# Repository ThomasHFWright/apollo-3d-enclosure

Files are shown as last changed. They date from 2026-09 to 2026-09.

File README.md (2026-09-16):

# Apollo R PRO-1 fixed-angle wall and corner enclosure

**Compact corner placement and independent wall offsets are included:** see the [corner guide](docs/COMPACT-CORNER.md). Each example retains its saved mounting settings.

A community enclosure for the **Apollo Automation R PRO-1**, designed with FreeCAD and Python. Print the direction you need: the mount has no ball joint or friction-fit backplate to slip under cable load. A bolted lid retains the main PCB on segmented rails, with space and ventilation for PoE and the optional radar/CO₂ modules.

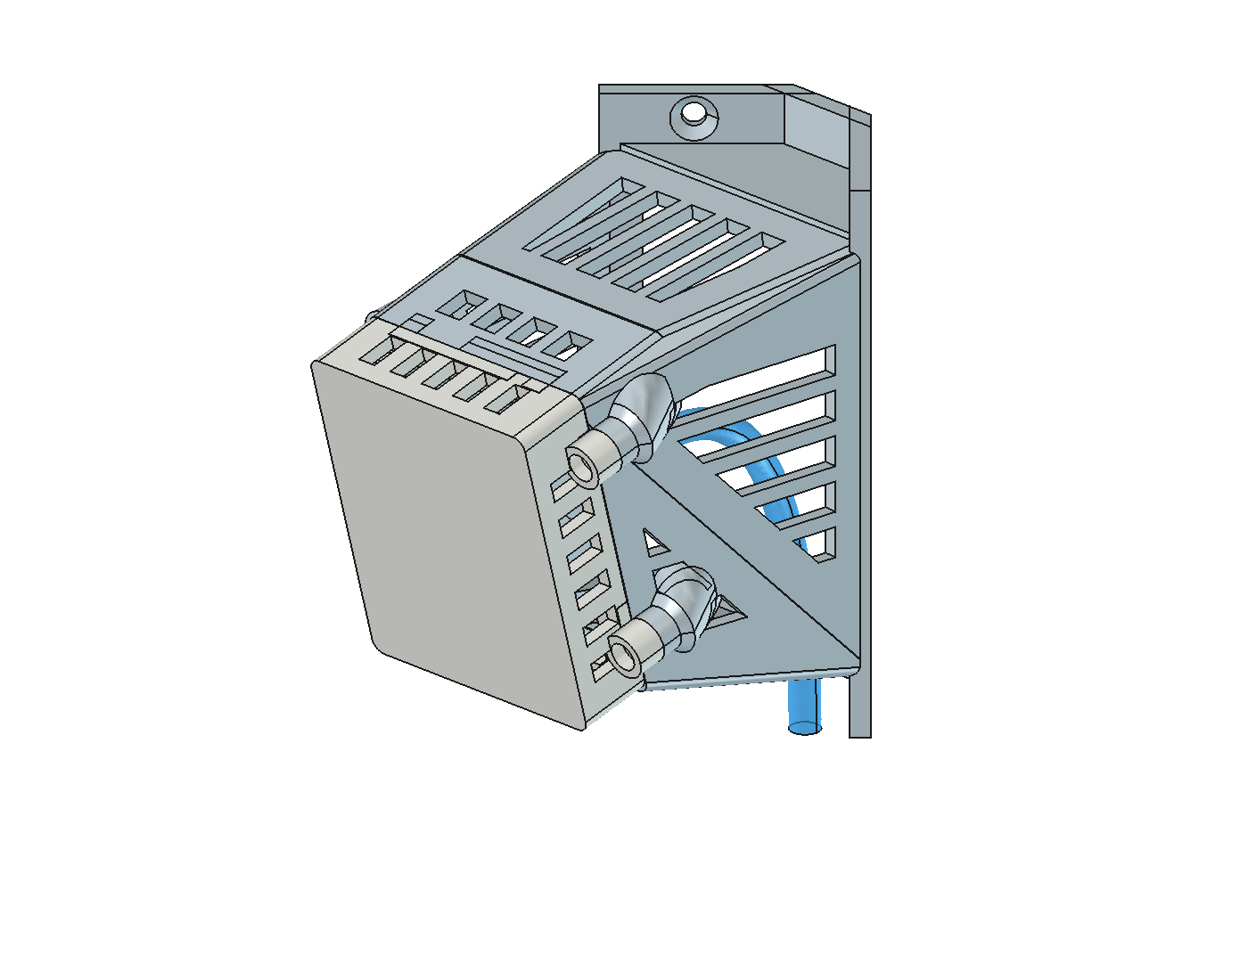
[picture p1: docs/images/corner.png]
Corner preset


*Cable-enabled corner demonstration with a 30 mm chamber. The blue cable is a reference preview, not a printed tube. Downloadable examples have cable routing disabled by default.*

**Only two STL files are needed to print an enclosure: one body and one lid.** The front sensor window is 1.2 mm thick; actual radar performance and long-term PETG behaviour still need checking in your installation.

This is an independent community project, not an official Apollo product. Thanks to [Apollo Automation](https://apolloautomation.com/products/r-pro-1) for providing the PCB and case references. See [attribution and reuse terms](ATTRIBUTION.md).

## What to download for printing

1. Download the **[shared lid.stl](output/lid.stl)**.
2. Choose **one body STL** from the examples below, or generate a body with your own angles in FreeCAD.

The default requested rear chamber is **10 mm**; the corridor snapshot retains its custom 1 mm depth. Cable routing is **off by default** in the main examples and new builds. The separately linked compact PoE demonstration has it enabled to illustrate the route. To enable the preview and intersection cutouts, set **CableEnabled = Yes** in FreeCAD and run the macro. The main image above intentionally shows this optional feature enabled.

Print one of each. The flat, corner, right-facing, left-facing and corridor downloads are **alternative examples of the body**, not extra parts to print. All supplied examples use the same lid; duplicate lid downloads have been removed from their folders.

The FreeCAD documents, STEP files, PCB reference and scripts are for editing or development. They are not additional printable parts. If you want to change parameters, download the whole repository and follow the FreeCAD workflow below.

## Edit your model in FreeCAD — recommended workflow

**Open a supplied FreeCAD model, edit its Parameters, then run the rebuild macro inside FreeCAD.** You do not need to edit Python or use a terminal for normal parameter changes.

1. Install **FreeCAD** and Qhull's **qconvex** executable. This project was tested with FreeCAD 1.1.3 on Linux; qconvex must be on the PATH visible to FreeCAD.
2. Download this whole repository using **Code → Download ZIP** and extract it. Keep `Rebuild.FCMacro` beside `build_mount.py`.
3. In FreeCAD, use **File → Open** to open a supplied `.FCStd`, such as `output/corner/apollo-mount.FCStd`. Use **File → Save As** for a working copy if you want to preserve the preset.
4. Select **Parameters – edit, then run Rebuild.FCMacro** in the model tree, then the **Data** tab in the Property view.
5. Double-click the values you want to change: for example **Yaw**, **Pitch**, **RearChamberDepth** or **CableEnabled**. Corner mounts also have **LeftWallOffset** and **RightWallOffset** for independent movement away from either wall; all current downloads already contain the full property set. Older personal copies gain new controls on their next rebuild. Enter lengths in millimetres and angles in degrees, and press Enter to finish each edit.
6. With that model's tab active, open **Macro → Macros…**. Set the macro location to the extracted repository folder if necessary, select **Rebuild.FCMacro**, and click **Execute**.
7. Wait for **“Apollo rebuilt…”** in FreeCAD's status bar/Report view, then inspect the updated model. The macro saves the new CAD and printable **body.stl** and **lid.stl**, plus STEP files, in **`output/custom/`**.
8. Copy that output folder to a named location to keep this version, then open the new STLs in your slicer and review them before printing.

**Editing a value, saving or pressing Recompute alone does not regenerate the geometry. Run the macro after changing parameters.** A successful rebuild overwrites matching files in `output/custom`, even when the source CAD file was saved elsewhere. Preserve any previous custom exports you want to keep before rebuilding. If the macro reports an error, correct it and rerun; old exports do not represent the new settings.

All supplied enclosure CAD files include every editable and calculated property; no preliminary rebuild is needed to reveal controls. Run the macro after changing values to update the geometry.

Existing supplied CAD files include the PCB reference, so the normal workflow above does not require decompressing the separate OBJ.

- **Full walkthrough and troubleshooting:** [FreeCAD guide](docs/FREECAD.md).
- **Every setting explained:** [editable and calculated parameters](docs/PARAMETERS.md).
- **Print an existing version:** use the model downloads below and the [printing guide](docs/PRINTING.md).
- **AI assistance and advanced automation:** [AI/developer guide](docs/AI-WORKFLOW.md).

## Body examples — choose one

These values were read from each saved CAD document for this publication. Saved models can have different mounting settings; their lid geometry was compared and is identical. Defaults in the parameter reference describe new CLI builds.

| Version | Mount | Yaw / pitch | Requested rear chamber | Cable | Files |
|---|---|---|---|---|---|
| Flat | Flat wall | 0° / 0° | 10 mm | Off | [CAD](output/flat/apollo-mount.FCStd) · [body](output/flat/body.stl) |
| Corner | 90° inside corner | 0° / 15° | 10 mm | Off | [CAD](output/corner/apollo-mount.FCStd) · [body](output/corner/body.stl) |
| Right-facing | Flat wall | +90° / 0° | 10 mm | Off | [CAD](output/yaw90/apollo-mount.FCStd) · [body](output/yaw90/body.stl) |
| Left-facing | Flat wall | −90° / 0° | 10 mm | Off | [CAD](output/yaw_minus90/apollo-mount.FCStd) · [body](output/yaw_minus90/body.stl) |
| Custom corridor | 90° inside corner | −39° / +4° | 1 mm | Off | [CAD](output/custom/apollo-mount.FCStd) · [body](output/custom/body.stl) |
| Entrance snapshot | 90° inside corner | −39° / +4° | 1 mm | Off | [CAD](output/Final-prints/entrance.FCStd) · [body](output/Final-prints/entrance.stl) |

The custom corridor and entrance snapshot use CompactCorner=Yes, LeftWallOffset=0 mm and RightWallOffset=12 mm. The flat, corner and ±90° presets retain standard placement.

The five preset folders also contain `body.step` and `assembly.step` for CAD editing. The shared lid is available as [STEP](output/lid.step) too. FreeCAD documents and assembly STEP files retain the lid in its assembled position for reference and rebuilding. All corner examples have a 10 mm corner-tip setback and top/bottom closures; their middle remains open. A requested 1 mm chamber does **not** mean the PCB is 1 mm from the wall: electronics space and any additional wall clearance are separate.

`output/custom` is also the macro's working export folder and is overwritten on a successful rebuild. Copy an example you want to keep before experimenting. The entrance snapshot is kept separately as an example of that workflow.

The STLs contain printable parts only. Native `.FCStd` documents include the original PCB as a visible guide. Orange clearance objects are simplified space reservations, not detailed models of the missing modules.

## More example views

### Corridor corner mount

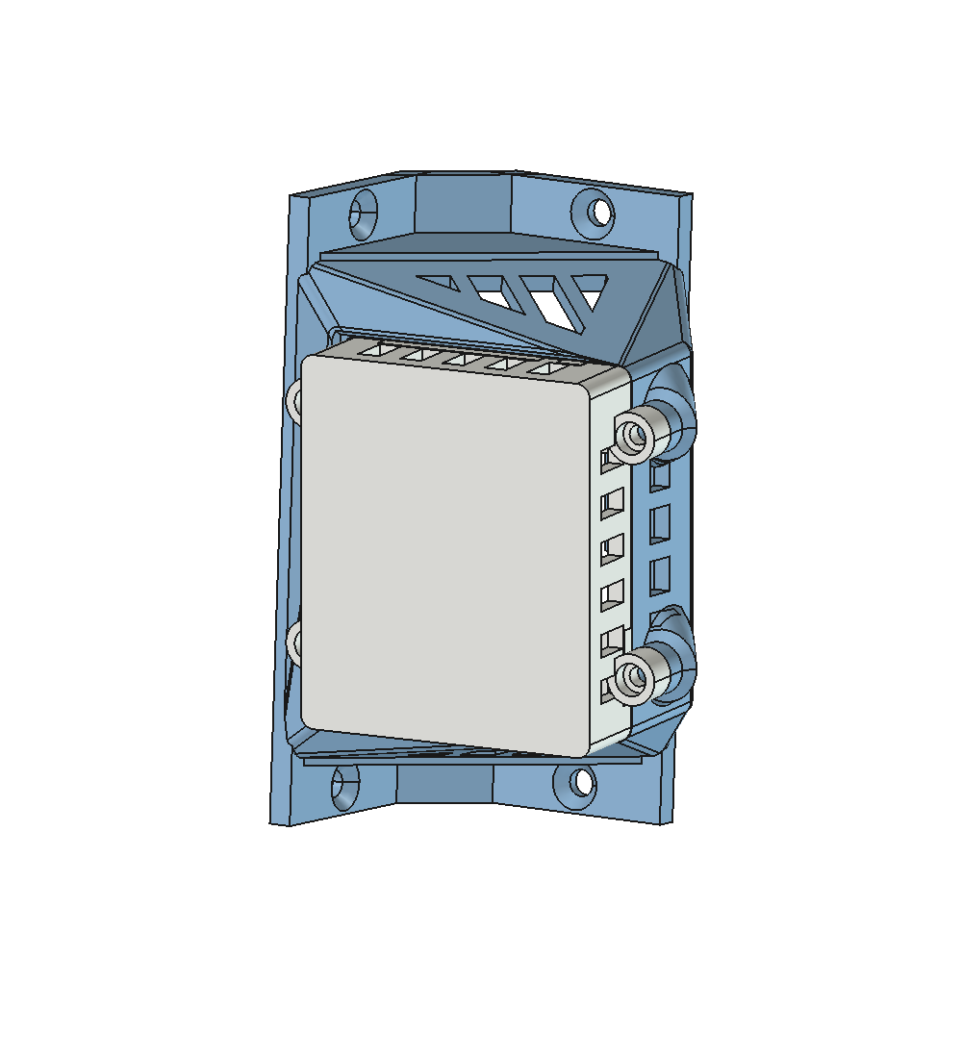
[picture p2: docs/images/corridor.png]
Corridor corner mount with 39-degree left yaw and 4-degree downward pitch


The [corridor example](output/Final-prints/entrance.FCStd) uses compact placement with **Yaw −39°, Pitch +4°**, 90° inside corner, requested rear chamber 1 mm, **RightWallOffset 12 mm**, LeftWallOffset 0 mm and cable disabled.

### Flat wall, facing right and slightly downward

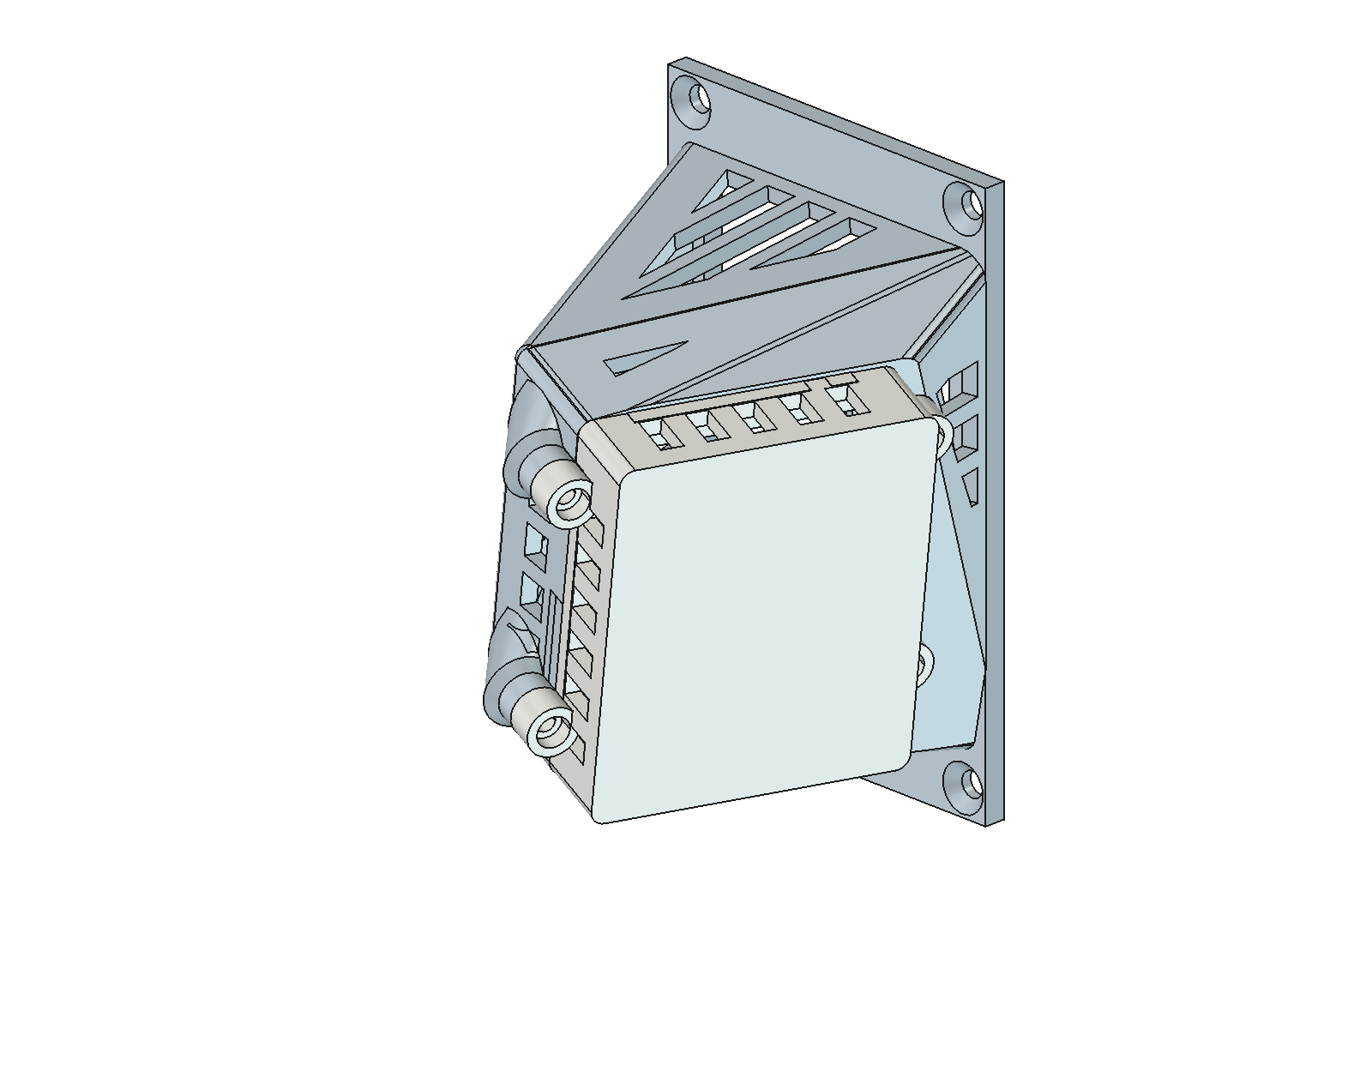
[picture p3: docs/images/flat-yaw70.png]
Flat-wall mount facing 70 degrees right with 10-degree downward pitch


Rendered from the flat preset with **Yaw +70° and Pitch +10°**, using the 10 mm default rear chamber with cable routing disabled. To make this version, open the flat CAD example in FreeCAD, change those two parameters and run the macro. Use −70° yaw to face the other way.

Both views show the assembled body and shared lid. PCB and cable reference objects are hidden to make the enclosure shape clear.

## How it works

`build_mount.py` calls FreeCAD's native Python geometry API: create solids, join them, subtract vents and clearances, then validate and export. Qhull's `qconvex` constructs the rear chamber envelope. No FreeCAD MCP server is required.

The model is **parametric through the generator**, not through a conventional sketch/Pad/Pocket feature history. Editing the `Parameters` object changes inputs; running `Rebuild.FCMacro` regenerates the shapes. Editing a value or pressing Recompute alone does not regenerate them.

## Advanced automation

For scripted builds, source-code changes or development tests, see the [AI/developer guide](docs/AI-WORKFLOW.md#advanced-command-line-builds). These are optional alternatives to editing parameters and running the macro in FreeCAD.

## Validation and limitations

The generator checks connected valid solids, reserved-component and wall collisions, body/lid overlap, closed STL meshes and the A1's 256 mm build-volume limit. These checks do not verify every physical module, print orientation, support choice or cable insertion manoeuvre.

Additional developer tests are described in the [AI/developer guide](docs/AI-WORKFLOW.md#required-verification). The full geometry suite can take several minutes and uses the included PCB reference document and official case STEP. Optional historical FEM scripts are included; see [AI workflow / structural screening](docs/AI-WORKFLOW.md#structural-screening). They are comparative solid-material calculations, not a prediction of heat-induced creep or printed PETG service life.

The supplied PCB mesh omits the plugged-in LD2450, optional LD2412 and CO₂ daughterboards. Front height 13.9 mm, rear height 16.9 mm and side overhang 1.4 mm came from physical measurements. Verify your revision with the body, lid, actual nuts and Ethernet connector before printing a batch.

## Contribute

Share your printer/material, parameter values, a photo of the problem and a small reproducible example in an issue or pull request. Keep PCB grips, fastener seats, vent reinforcement and cable clearances intact when changing the chamber. Please distinguish geometric validation from actual fit and sustained-PoE testing.

## License

Shared under [CC BY-NC-SA 4.0](LICENSE.md): attribute the creators, use noncommercially, and share adaptations under the same terms. See [ATTRIBUTION.md](ATTRIBUTION.md) for Apollo's original files and the changes made here. Apollo names and logos remain their owners' marks; this project is not endorsed by Apollo.

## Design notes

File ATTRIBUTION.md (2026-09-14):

# Attribution and reuse

## Apollo Automation references

The original R PRO-1 PCB mesh and official case reference are by **Apollo Automation**:

- [R PRO-1 product](https://apolloautomation.com/products/r-pro-1)
- [Official Printables model, ID 1349017](https://www.printables.com/model/1349017-apollo-automation-r-pro-1-dual-mmwave-multisensor)
- [Apollo source/CAD links](https://wiki.apolloautomation.com/homey/products/general/links/)
- [Apollo R_PRO-1 repository and license](https://github.com/ApolloAutomation/R_PRO-1)

The downloaded Printables model description, dated 6 April 2026, lists `r-pro-1-pcb.obj` and specifies **Creative Commons Attribution–NonCommercial–ShareAlike 4.0 International**. The same license text is published in Apollo's R_PRO-1 repository. That text is included as LICENSE.md.

Files retained here:

- `r-pro-1-pcb.obj.gz`: losslessly compressed original OBJ; decompress to restore it. No geometry edits.
- `r-pro-1-pcb-reference.FCStd`: imported and coloured reference assembly made from that mesh. It does not add detailed geometry for the missing daughterboards.
- `SourcePCB` within the enclosure `.FCStd` documents: the same reference mesh, repositioned to match each generated enclosure.
- `apollo-automation-r-pro-1-dual-mmwave-multisensor-with-optional-co2-addon-model_files/r_pro-1_case.step`: official front-case reference used by the thickness check.

## Community enclosure

**Thomas H. F. Wright / ThomasHFWright**, with AI-assisted FreeCAD/Python development, created the configurable fixed-angle wall/corner enclosure and accompanying generator, tests and guides.

Changes relative to the reference product include a fixed printed mount, configurable yaw/pitch and corner setback, ventilated connecting chamber, extended PCB rails and component notches, bolted cover and recessed hardware, and conditional reinforced cable openings. This is a community design, not Apollo's original enclosure, an official release or a claim of Apollo endorsement.

This repository is shared under **CC BY-NC-SA 4.0**. Credit Apollo for its references and ThomasHFWright for the enclosure/generator; identify modifications, keep reuse noncommercial and distribute adaptations under the same terms. The authoritative terms are in [LICENSE.md](LICENSE.md), with a [plain-language summary from Creative Commons](https://creativecommons.org/licenses/by-nc-sa/4.0/). Third-party trademarks remain with their owners.

FreeCAD, OpenCascade, Qhull, Gmsh, CalculiX and OrcaSlicer are separate dependencies under their respective licenses. Their binaries are not bundled here.

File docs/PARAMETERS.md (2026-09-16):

# Complete parameter reference

The tables cover every editable entry in `build_mount.py:PARAMETERS`. Defaults below are **generator defaults**; the value in your saved FreeCAD document is what the GUI rebuild uses. All numbers are millimetres unless marked as angles; boolean values appear as Yes/No. In FreeCAD, select **Parameters → Data**, edit the values, then choose **Macro → Macros… → Rebuild.FCMacro → Execute**. Follow the [FreeCAD walkthrough](FREECAD.md) for setup, saving versions and troubleshooting.

## Coordinates and interactions

PCB X is left/right, Y is bottom/top, and Z points through the front cover. The PCB is 44.474688 × 56.974716 mm, 1.586157 mm thick; the rear PCB face is Z=0 and front face Z=PCB_T. PCB coordinates rotate with the device. The mounting frame remains fixed, with +Z toward the room; in corner mode its reference plane bridges the wall pads. LeftWallOffset and RightWallOffset add independent movement away from the two walls after automatic placement. They do not rotate the PCB or move the mounting frame. In standard mode, RearChamberDepth is measured to the electronics bay, not directly to the PCB; in compact mode it adds forward stand-off from the nested position.

Positive pitch tilts down. Positive yaw rotates front-facing +Z toward +X. A corner mount at zero yaw faces its corner bisector. Viewing from behind reverses apparent left/right. The CompactCorner option changes the placement rule and chamber-depth datum as described below. Rotating the PCB can increase stand-off to avoid walls; it also shifts the PCB sideways. Parameters interact, so listed ranges alone do not guarantee a valid combination.

When CableEnabled is No, other Cable-group inputs are ignored. Module, structural and wall checks continue. All active numeric inputs must be finite.

## Mount

| Parameter | Default | Meaning and how to use it |
|---|---:|---|
| `Corner` | No | Yes selects two angled wall-contact pads; No selects a flat-wall frame. Rebuild and inspect screw access after changing. |
| `CompactCorner` | No | Corner mounts only. Yes balances the rigid holder/cover and rear component envelope between the two walls, allowing the chamber to taper into the hollow corner. Reserves the four wall-screw bearing pads when positioning the PCB. Only the chamber is trimmed at the lid seating plane; wall-contact frame corners remain intact, even where they extend past that plane beside the lid. Tapered wedges close gaps between the chamber and frame and meet the lid seating edge with 0.2 mm clearance for the lid and retaining lips, without moving the PCB. RearChamberDepth becomes extra forward stand-off from this calculated placement. Enable CableEnabled to include the provisional plug; cable-off does not reserve a plug or bend. Inspect the complete route and wall-entry needs. |
| `CornerAngle` | 90 | 60–150°. Measure the included wall angle, not the PCB aim. 90° is a square inside corner. Validated even in flat mode. |
| `CornerSetback` | 10 | Nonnegative. For corner mode, removes the rear tip along the bisector to clear rounded plaster. A geometry-dependent maximum protects screw material (about 17.59 mm at the default 90°/70 mm frame). 0 restores the sharp tip; ignored on flat mounts. |
| `CornerSpine` | No | No retains 4 mm thick closures at the top/bottom only. Yes fills the same flat-backed strip over the height. Relevant only to corner mounts with nonzero setback. |
| `Yaw` | 0 | −90 to +90°. Rotation about model Y. 0 is straight ahead for flat mounts and along the corner bisector for corner mounts. Standard mode shifts the PCB sideways by half its width × sin(yaw); compact corners balance the wall clearances instead. Verify direction visually. |
| `Pitch` | 0 | −40 to +40°. Positive tilts down, negative tilts up. Combined with yaw; the geometry may move forward to avoid the wall. |
| `RearChamberDepth` | 10 | Must be positive. Sets the rear chamber length, excluding the electronics bay. With CompactCorner=Yes, this is extra forward stand-off from the nested position instead. Short values can omit short vents. Rotated components may still need extra stand-off; inspect AdditionalWallClearance. It is not the full wall-to-PCB distance. |
| `LeftWallOffset` | 0 | Nonnegative extra perpendicular distance from the left wall, viewed facing into the corner. Moves the complete PCB/lid assembly parallel to the right wall, keeping its distance from that wall fixed. Applies to standard and compact corners; ignored for flat walls. |
| `RightWallOffset` | 0 | Nonnegative extra perpendicular distance from the right wall, viewed facing into the corner. Moves the assembly parallel to the left wall, keeping its distance from that wall fixed. 0 restores the calculated position. Applies to both corner modes; ignored for flat walls. |

## Clearances

| Parameter | Default | Meaning and how to use it |
|---|---:|---|
| `FrontHeight` | 13.9 | Positive. Measure from the main PCB front face to the tallest module or pin; the default 13.9 includes the short radar module pins. Increasing it deepens the cover. |
| `RearHeight` | 16.9 | Positive. Main PCB rear face to the back of the PoE socket. Also locates the plug start plane; changing this alters cable and bay geometry. |
| `SideOverhang` | 1.4 | Nonnegative. Additional component width outside each PCB side. The measured black part extends 1.4 mm; this reserve is applied symmetrically. |
| `TopOverhang` | 0.5 | Nonnegative. Additional component height above the PCB top edge. The measured installation has at most about 0.5 mm. |
| `SideClearance` | 1 | Positive. Gap beyond the board/component outline; changes the enclosure width/height. This is separate from the close-fitting PCB RegistrationGap. |
| `FrontClearance` | 1.5 | Positive. Additional room above the tallest front component/pin, before the cover skin. |
| `RearClearance` | 3 | Positive. Extra bay depth behind the rear component envelope. It changes the PCB distance while preserving the requested rear-chamber input. |

## Retention

| Parameter | Default | Meaning and how to use it |
|---|---:|---|
| `BoardSlotGap` | 0.3 | Positive. Vertical free play above the PCB before the lid keeper contacts it. Too little can clamp the board; too much allows movement. Check the PCB fit between the body and lid. |
| `RegistrationGap` | 0.3 | Positive and strictly less than EdgeBite. In-plane clearance at locating stops. Too large lets the PCB slide off its ledges. |
| `EdgeBite` | 0.8 | Greater than 0, at most 1.2 mm. Rail overlap onto the PCB edge. More overlap is not always better: nearby components must remain clear. |
| `EdgeReliefMargin` | 0.8 | Positive. Extra gap around mapped edge components when generating the segmented rails. Increasing it shortens supporting rail segments. |
| `BlackReliefStartY` | 0 | PCB-centred Y coordinate. Together with EndY defines an extra rear-left rail interruption. Must satisfy −H/2 ≤ start < end ≤ H/2. This location is a conservative keep-out, not detailed optional-module CAD. |
| `BlackReliefEndY` | 21 | Upper end of the extra black-part interruption. EdgeReliefMargin expands the blocked interval. Physical PCB height H is 56.974716 mm. |
| `CO2ReliefSize` | 13 | Nominal square side, at least 12.901624 mm to reach the PCB edge. Centred on the connector at X=15.786532, Y=−6.861016. The cut extends outward to the inner enclosure wall across the holder depth. |
| `CO2ReliefClearance` | 0.8 | Nonnegative, added on EACH side. Default square width is 13 + 2×0.8 = 14.6 mm before its outward extension. The cut must retain the outer wall and avoid PCB corners; excessive size/clearance is rejected. |
| `LowerContactY` | -20.062 | Y coordinate of the lower lid screw pair, in PCB coordinates. Must remain strictly inside −H/2+5 .. H/2−5 mm. Keep the lower and upper pairs well separated; inspect actual boss/rail fit if moving them. |
| `UpperContactY` | 21.938 | Y coordinate of the upper screw pair, with the same corner exclusion as LowerContactY. This relocates both left/right fastener housings at that height. |
| `FastenerSize` | M3 | Dropdown: M2 or M3 only. Changes bolt holes and ordinary hex-nut pockets together. M4/M5 do not fit the existing housings. Screw-head dimensions are independent; enter dimensions of your actual head. |
| `NutClearance` | 0.4 | Nonnegative TOTAL extra width across flats, not per side. Default M3 pocket is 5.9 mm across flats. Nut depth is nominal thickness + 0.5 mm. Excessive width is rejected to stop rotation and retain the access-throat/boss wall. |
| `ScrewClearance` | 0.4 | At least 0.1 mm TOTAL extra bolt-hole diameter. Default M3 hole is 3.4 mm. Excessive diameter is rejected to retain nut bearing material. |
| `ScrewHeadDiameter` | 5.3 | Measured head diameter, before clearance. When recesses are enabled it must exceed the bolt-hole diameter by at least 1.6 mm, and diameter + clearance must be at most 6.6 mm. |
| `ScrewHeadDepth` | 2.8 | Nonnegative. Head height before depth allowance; 0 disables recesses. A raised rim surrounds the head, preserving the existing 3.2 mm seat instead of thinning it. |
| `ScrewHeadClearance` | 0.4 | Nonnegative TOTAL diameter allowance; half is added to depth. Defaults produce a 5.7 mm diameter × 3.0 mm deep recess. It does not set nut fit. |
| `NutAccessDiameter` | 18 | Positive. Nominal finger pocket width, provisionally 18 mm. The opening is flattened near top/bottom panels. Larger values can collide with the enclosure; insert nuts before the PCB. |
| `NutAccessDepth` | 12 | Positive. Inward-sloping approach depth behind the nut seats. Exterior hood feet may continue farther to finish flush inside the chamber. Check access with real fingers/tweezers. |

## Printing

| Parameter | Default | Meaning and how to use it |
|---|---:|---|
| `WallThickness` | 2.8 | At least 2.4 mm. Governs perimeter, chamber, hoods and several clearances; changing it can change the outside appearance. It is not a slicer wall-count setting. |
| `FrontSkin` | 1.2 | At least 0.8 mm. Cover front-wall thickness, default 1.2 mm. The supplied official front measured 1.25–1.75 mm. Increasing it above 1.25 fails the comparison test; no thickness guarantees RF performance. |
| `CornerRadius` | 2.5 | 0 .. WallThickness. Circular outer rounds, not a flat chamfer. 0 gives sharp outer corners. Inner/base junctions remain plain; locally invalid rounds may be omitted. |
| `VentSlot` | 6 | Positive. Width of ventilation openings. Larger slots reduce material and change appearance; preserve strong edges/ribs and inspect support needs. |
| `VentRib` | 3 | At least 2.4 mm. Material between ventilation slots; changes the slot spacing and appearance. Slots are also kept away from fasteners and panel edges. |
| `SideVentOffset` | 4 | 0–10 mm. Shifts side-wall slot layout upward to leave more solid material near the lower edge. It is not a global vent margin. |

## Cable

| Parameter | Default | Meaning and how to use it |
|---|---:|---|
| `CableEnabled` | No | No skips ALL cable checks, previews, cutouts and cable reinforcement; saved cable values are retained for re-enabling. PCB/module/wall checks remain active. Hiding CablePreview alone does not disable processing. |
| `PortX` | -0.025 | Socket-centre X in PCB coordinates. Source default −0.025 mm. Change only after checking the real connector position. |
| `PortY` | -8.907 | Socket-centre Y in PCB coordinates. Source default −8.907 mm. This is not the cable entry position on the wall. |
| `PlugWidth` | 17 | Positive. Provisional rigid plug/boot cross-section width. Measure your plug, including moulded boot; the passage must contain it. |
| `PlugHeight` | 18 | Positive. Provisional rigid plug/boot/latch height. Rounded passage corners must also clear the rectangular envelope. |
| `PlugLength` | 15 | Positive. Socket opening to flexible-cable start. Default starts the bend 15 mm behind the socket. Include the boot and protruding rigid plug length. |
| `CableDiameter` | 6 | Positive. Physical wire outside diameter, used for the visible cable and actual-material-intersection test that triggers a cut. |
| `CableClearance` | 0.8 | Positive radial allowance. The rounded hole must contain the wire diameter plus clearance. This does not enlarge the displayed physical wire. |
| `CableHoleWidth` | 20 | Positive clear width of the connector passage; independent of CableDiameter. Both width and height must clear the cable and provisional plug. |
| `CableHoleHeight` | 22 | Positive clear height of the connector passage. An opening only cuts body material where the physical wire actually intersects remaining geometry, not where the larger passage is merely nearby. |
| `CableHoleRadius` | 3 | Nonnegative and smaller than half the smaller hole dimension. Large corner radii can clip the plug rectangle; the generator checks this. |
| `CableEntryX` | 0 | Cable entry X in the fixed mounting frame. 0 is centred horizontally. Unlike PortX, this is not rotated with the PCB. |
| `CableEntryY` | -68 | Entry Y in the fixed mounting frame. Negative is toward the model bottom. Default −68 lies below the frame. |
| `CableEntryDepth` | 8 | Preferred Z offset ahead of the mounting-frame front plane. Negative values can place the route behind the model, assuming a real wall opening there. AutoCableRoute may reduce this value. |
| `AutoCableRoute` | Yes | Yes searches rearward in 5 mm steps up to 200 mm, then tries 1.5× and 2× handle lengths. Preserves entry X/Y/direction and does not increase RearChamberDepth. No uses the exact requested route inputs. |
| `CableAzimuth` | -90 | Degrees in the mounting frame: 0 right, +90 up, −90 down. Sets outgoing direction from socket toward entry. Use with elevation to approach from different directions. |
| `CableElevation` | 0 | Degrees out of the mounting plane: 0 parallel to the wall/reference plane, positive toward the room. At ±90 the azimuth has no directional effect. |
| `CableTangentLength` | 34 | Positive Bezier handle length controlling the sweep. Longer is not always better; inspect the full route. AutoCableRoute may multiply it; see ActualCableTangentLength. |
| `MinBendRadius` | 20 | Positive minimum cable-centreline bend radius; use your cable specification. The larger hole/rim also imposes a radius bound, so reducing this alone may not make a tight route valid. Curvature checking is sampled. |
| `CableRimWidth` | 3 | Positive material margin around actual cable intersections, including across nearby vent slots. This reinforces the opening; it never creates a standalone printed cable tube. |

## Calculated, read-only properties

These update on a successful rebuild/export; change the driving inputs instead. Cable results are zero placeholders when the cable is disabled.

| Property | Meaning / driving inputs |
|---|---|
| `BoardDistance` | Actual PCB-centre Z offset ahead of the rear mounting-frame front plane, including bay depth, added wall clearance and the forward component of LeftWallOffset/RightWallOffset. Driven by those offsets, RearChamberDepth, module dimensions and orientation. |
| `PCBOffsetX` | Standard mode: 44.474688 / 2 × sin(Yaw). Compact corners instead balance the two wall-clearance bounds, which can shift the PCB in the opposite direction. Both corner modes then include the sideways component of LeftWallOffset/RightWallOffset. |
| `AdditionalWallClearance` | Automatic standard-mode extra forward stand-off, included in BoardDistance; excludes the manual wall offsets. Zero in compact mode because that mode calculates placement directly. |
| `CornerDepthSaving` | Reduction in forward PCB position versus standard placement with the same inputs. Positive means closer along the corner bisector; it is not the perpendicular distance to either wall. Zero outside compact mode. |
| `WallPlateWidth` | Nominal plate width, default 70 mm; depends on enclosure width, not automatically enlarged for yaw/pitch. |
| `WallPlateHeight` | Plate height including mounting ears, default 108 mm. |
| `NutPocketAcrossFlats` | Nominal nut width + NutClearance: M3 default 5.9 mm; M2 default 4.4 mm. |
| `NutPocketDepth` | Nominal nut thickness + fixed 0.5 mm allowance: M3 2.9 mm, M2 2.1 mm. |
| `ScrewHoleDiameter` | Nominal thread diameter + ScrewClearance: M3 default 3.4 mm, M2 default 2.4 mm. |
| `ScrewHeadRecessDiameter` | ScrewHeadDiameter + ScrewHeadClearance; 0 with head recess disabled. |
| `ScrewHeadRecessDepth` | ScrewHeadDepth + half ScrewHeadClearance; 0 with head recess disabled. |
| `ActualCableEntryDepth` | Entry depth actually used after automatic routing. Negative can require an opening behind the mount. |
| `ActualCableTangentLength` | Bezier handle length actually used after automatic routing. |

## Adjust clearance from either corner wall

1. Select **Parameters → Data → Mount** in FreeCAD. Left and right are viewed facing into the corner.
2. Increase **LeftWallOffset** to move away from the left wall while keeping the distance from the right wall fixed. Increase **RightWallOffset** for the opposite movement. Values are extra perpendicular clearance in millimetres, not total wall-to-PCB distances.
3. Run **Macro → Macros… → Rebuild.FCMacro → Execute**, then inspect the enclosure and your connector clearance. The PCB angle and mounting frame stay fixed while the chamber adjusts.

The corridor example uses **RightWallOffset = 12 mm**, **LeftWallOffset = 0 mm**, **RearChamberDepth = 1 mm**, **Yaw = −39°** and **Pitch = 4°**. At a 90° corner, that right-wall offset moves the PCB about 8.49 mm sideways and 8.49 mm forward while preserving its left-wall distance. CableEnabled is No, so the cable preview and automatic connector checks are disabled.

Set either offset back to **0** to remove its extra movement. Both offsets work with standard and compact corner placement; flat-wall mounts ignore them and use **RearChamberDepth** instead. RearChamberDepth on a corner adds movement along the corner bisector, increasing clearance from both walls together.

## Legacy names and fixed dimensions

- Old `BoardDistance` inputs are migrated to RearChamberDepth when reading legacy documents. Do not edit the new calculated field.
- Old `CornerChamfer` maps to CornerRadius. The current geometry uses circular rounds.
- Old `CableGuide` and `ContactLength` properties are removed during rebuilding; no printed cable tube remains.
- PCB dimensions, source alignment, mapped component bands, mounting-plate thickness (4 mm), wall-screw bore (4.6 mm), boss outside diameter (9 mm), holder depth (6.6 mm), cover screw-seat thickness (3.2 mm) and nut depth allowance (0.5 mm) are code constants, not exposed settings. An AI/source edit is needed to change those, followed by geometry/fit validation.

## Common changes

- Aim along a corridor: edit Yaw and Pitch; confirm direction in 3D. A target 6.2 m away, 0.62 m from the side wall and 0.45 m below the sensor gives approximately −39° yaw / +4° pitch for the illustrated 90° corner arrangement. Mirrored installations can require the opposite yaw sign.
- Slide within a corner: increase LeftWallOffset or RightWallOffset independently. At a 90° corner, a 5 mm offset moves 3.536 mm sideways and 3.536 mm forward, adding exactly 5 mm perpendicular distance from the selected wall. The other wall distance stays fixed. Both offsets at 5 mm move 7.071 mm forward with no sideways movement. Keep them at 0 to retain the previous position. Large offsets can still fail enclosure/lid/fastener fit checks; offsets never silently reposition the assembly to compensate.
- Shorten the chamber: reduce RearChamberDepth; inspect AdditionalWallClearance. Do not reduce measured module heights to force a smaller enclosure.
- Clear rounded plaster: increase CornerSetback within its allowed range. Use CornerSpine only if a full central strip is wanted.
- Remove the cable completely: CableEnabled = No, then rebuild. To keep the route but hide it, use Space on CablePreview instead.
- Loosen nut fit: increase NutClearance slightly and rebuild the body. This is total across-flats allowance, unlike CO2ReliefClearance which is per side.
- Change head recesses: use measured ScrewHeadDiameter/Depth. Changing M2/M3 does not automatically measure or select a matching head.

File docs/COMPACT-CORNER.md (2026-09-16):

# Compact corner mount

Included on `main`. Compact placement brings the R PRO-1 closer to an inside corner while preserving the existing PCB holders, cover and mounting pads. It remains an opt-in setting; each download retains its own saved configuration.

## Try it in FreeCAD

Open [the compact corridor CAD](../output/compact-corner-poe/apollo-mount.FCStd) using the included generator and macro. It starts with:

| Parameter | Value |
|---|---:|
| Corner | Yes |
| CompactCorner | Yes |
| Yaw / Pitch | −39° / +4° |
| CornerAngle / CornerSetback | 90° / 10 mm |
| RearChamberDepth | 1 mm |
| CableEnabled | Yes |

Select **Parameters → Data**, change the values, then run **Macro → Macros… → Rebuild.FCMacro → Execute**. `RearChamberDepth` now adds forward stand-off from the calculated compact position; increase it if your real cable needs more space. It no longer measures an empty gap ahead of the old flat rear frame when CompactCorner is enabled.

**Independent wall movement:** edit `LeftWallOffset` or `RightWallOffset` in Parameters → Data, then run the macro. Left/right are viewed facing into the corner. Each value adds that many millimetres of perpendicular distance from its wall while keeping distance from the other wall fixed; the PCB angle and frame stay unchanged. Defaults are 0. These controls also work for standard corner mounts. Flat mounts use RearChamberDepth and ignore these two offsets.

`CompactCorner = No` restores the normal placement rules. It defaults to No and has no effect on flat-wall mounts. All current enclosure downloads already include the complete editable and calculated property set. No initial rebuild is needed to expose the controls. Older personal copies gain missing properties on their next rebuild.

Only [the new body STL](../output/compact-corner-poe/body.stl) and [the existing shared lid](../output/lid.stl) are needed to print. The compact example folder also provides body STEP and assembly STEP files. Rebuilds still write into `output/custom`; preserve any work there first.

## What changed

The original placement used a full-depth, full-height bounding box including the widest screw housings, and the same sideways shift used for flat-wall mounts. The chamber also stopped at the flat plane across the front of the corner bracket, leaving the space behind it unused.

Compact mode separates the rigid PCB holder, cover and screw housings from the rear component-clearance envelope, balances clearance against both walls, and lets the chamber taper into the hollow corner. The empty rear bay no longer acts as a full-width rigid box during placement. The back stays open: the existing corner frame supplies the wall-contact material, with end closures and screw supports retained. The mounting pads and screw centres stay in place. The PCB, lid and retention rails remain rigid. This is the minimum of the conservative placement envelopes plus the requested extra stand-off, not proof of the absolute smallest possible enclosure.

Only the chamber is trimmed at the lid seating plane. The complete wall-contact frame stays intact, including corners that extend past that plane beside the lid. Solid wedges join the trimmed chamber back to the frame wherever the cut would leave a triangular gap. They taper down to the lid seating edge at 45°, with curved relief around the screw housings, instead of stopping at a fixed width and leaving a step. A 0.2 mm clearance protects the lid and retaining lips; the back stays open. PCB placement is unchanged; the lid, rigid PCB ring and screw bearing pads retain their clearance. The existing corner-tip setback and intentional cable passages still apply.

The provisional rigid plug envelope is included when CableEnabled is Yes. The existing route generation and reinforced intersection cutouts then run in the new position. When CableEnabled is No, cable parameters remain ignored; that setting does not establish plug or bend clearance.

## Cable assumption

This prototype assumes a cable arriving through the wall behind the PCB, or a sufficiently flexible cable whose real clearance you will check. The saved cable-enabled route uses the existing 20 mm bend-radius input and automatically places its entry behind the wall (ActualCableEntryDepth = −62 mm relative to the rear-frame front plane). It therefore needs a real wall opening if followed as drawn.

The geometry checks clear the provisional 17 × 18 × 15 mm connector and displayed cable from the body. They do not establish that an external stiff cable can bend down in the same space. Use RearChamberDepth to add space, or configure the route for the actual cable. No assumed cable bend limit has been reduced.

## Comparison with the recent corridor print

Both versions keep −39° yaw, +4° pitch and the requested depth value 1 mm. The original print has cable processing off; the prototype explicitly enables it to check the provisional plug/route.

| Measure | Original | Compact |
|---|---:|---:|
| PCB centre X in fixed frame | −13.99 mm | +1.08 mm |
| PCB centre Z from theoretical corner | 76.43 mm | 59.46 mm |
| Forward projection reduction | — | **16.97 mm** |

The centre shifts sideways by 15.07 mm as well as moving back. The 16.97 mm figure is along the corner bisector, not perpendicular to either wall. Read-only `CornerDepthSaving` compares the two placement rules at the same parameter values; `BoardDistance` still reports actual PCB distance ahead of the rear-frame front plane. `AdditionalWallClearance` is zero in compact mode because placement is calculated directly.

With the redundant rear panels removed, the compact body's solid CAD volume is about 51.2 cm³ versus 55.7 cm³ for the original cable-off print. Actual sliced filament depends on orientation, infill and supports.

### Top views — same camera and scale

| Original | Compact |
|---|---|
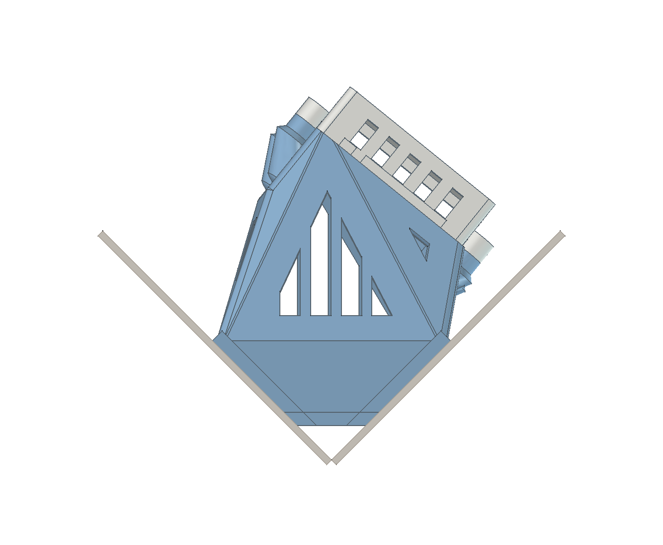
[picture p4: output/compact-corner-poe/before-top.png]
Original corridor mount from above
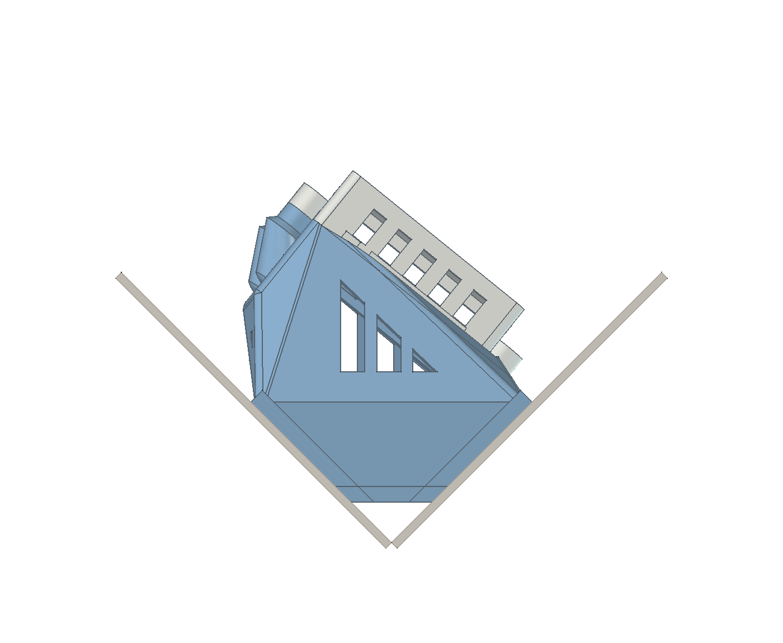
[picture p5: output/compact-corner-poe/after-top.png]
Compact corridor mount from above
|  |  |

Beige surfaces indicate the two wall planes for comparison; they are not exported printable parts.

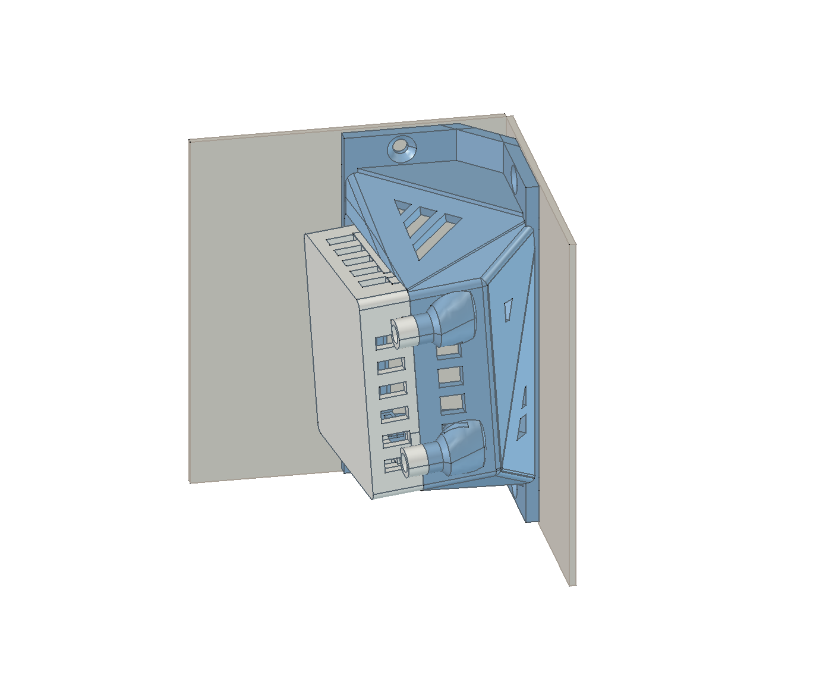
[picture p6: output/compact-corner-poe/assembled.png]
Compact corner assembly


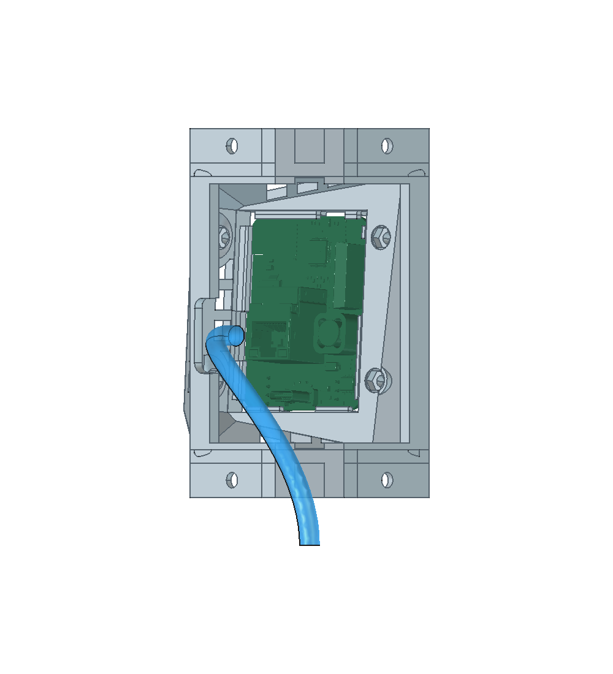
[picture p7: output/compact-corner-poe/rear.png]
Open back with PCB and cable references


## Straight corner with 15° downward pitch

[Open this FreeCAD example](../output/compact-pitch15/apollo-mount.FCStd) or use its [body STL](../output/compact-pitch15/body.stl) with the shared lid. It uses the corner preset with CompactCorner=Yes and RearChamberDepth=1 mm; yaw is 0° and pitch is +15°.

Separating the rear clearance envelope from the rigid holder reduces the PCB-centre Z from 68.34 to 60.85 mm: **another 7.49 mm closer** than the first compact implementation. The measured rear height and the existing broad component/air clearances remain reserved. CableEnabled is No in this example, so it does not check connector or cable routing. Increase RearChamberDepth when the real cable needs more room.

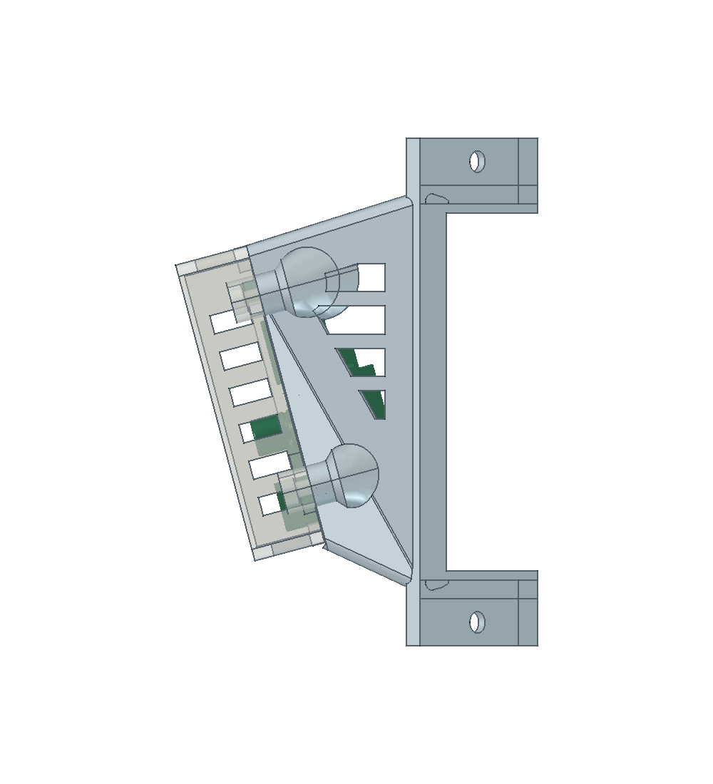
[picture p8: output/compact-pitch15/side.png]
Compact corner at yaw 0 and pitch 15


## Combined yaw and pitch

At yaw −39° and pitch 15°, keeping all four screw mounts behind the lid requires 7.56 mm more forward stand-off than the previous recessed-lid prototype, together with a 7.56 mm sideways shift. The PCB centre is now Z=63.86 mm, still 13.37 mm closer than the standard placement. The complete wall-contact frame is retained and the back stays open. The mirrored +39° case receives the equivalent adjustment.

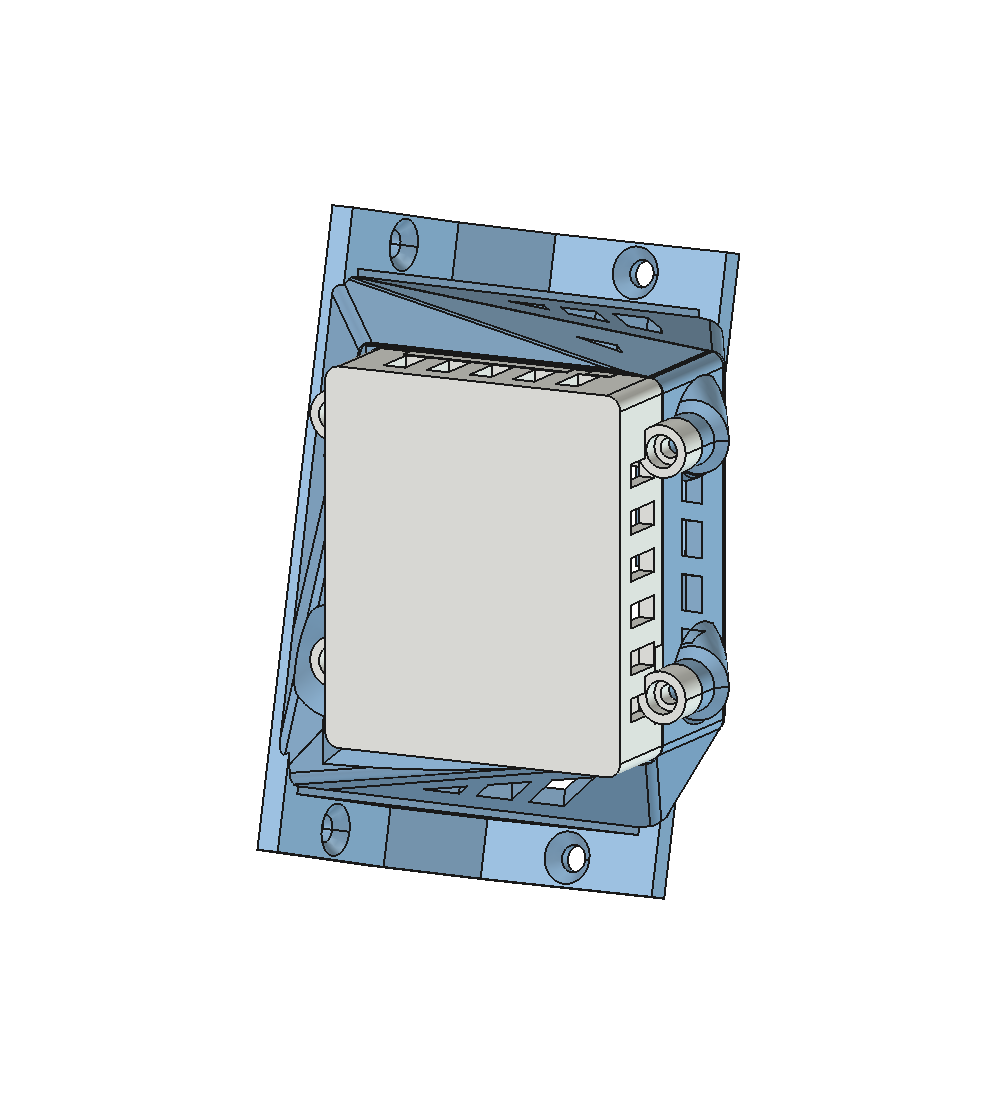
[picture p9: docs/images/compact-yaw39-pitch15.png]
Lid above the body at yaw minus 39 and pitch 15


## Checks

Run `python test_compact_corner.py` with the installed FreeCAD libraries. It checks the flat reference against the standard generator, compact ±39° cable-enabled examples, ±39°/15° cases with explicit checks that the chamber stays behind the lid seating plane while the whole wall-contact frame and local closing wedges remain intact, straight/tilted, −70° and ±90° examples, a 110° corner, unchanged lid/PCB contact geometry, CO₂ clearance, material probes in the previously open triangular junction and along the taper to the lid seat, unchanged PCB placement, wall-screw bores and bearing pads, an unobstructed rear opening and valid connected closed meshes. All eight published saved CAD examples are rebuilt from their own parameters into temporary folders, checking both exported parts, bed placement and A1 bounds. Standard flat/corner bodies and lids are also compared geometrically with their saved originals. A further check confirms that adding 5 mm to RearChamberDepth moves the PCB forward exactly 5 mm while preserving connector clearance.

The saved example is generated by executing the actual FreeCAD GUI rebuild macro in an isolated directory, then checking its saved parameters and exports. The project owner reports that the latest printed model worked well. This is a fit/use observation, not a long-term thermal-creep test; existing FEM reports do not validate the changed compact body.

`python test_wall_offsets.py [saved.FCStd]` checks independent wall movement, 90°/110° examples, both corner placement modes, unchanged lid/frame geometry, input validation and both printable exports.

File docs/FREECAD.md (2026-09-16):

# Edit parameters and rebuild inside FreeCAD

This is the **primary workflow** for configuring an enclosure: edit the supplied model's **Parameters → Data** values, then execute **Rebuild.FCMacro from FreeCAD's Macro menu**. Python editing and terminal build commands are only needed for advanced development or automation.

Current enclosure downloads already contain all controls, including CompactCorner, LeftWallOffset and RightWallOffset. Open the file and edit Parameters → Data immediately; run Rebuild.FCMacro after changing values. Older personal copies gain missing controls on their next rebuild.

## First use

1. Install FreeCAD and Qhull's `qconvex` executable. This project was tested with FreeCAD 1.1.3 on Linux. Ensure `qconvex` is on the `PATH` visible to FreeCAD; a sandboxed installation may need extra access. Merely opening the saved models needs no Qhull.
2. Download and extract the **whole repository**, or clone it. Keep `build_mount.py` and `Rebuild.FCMacro` together in the root directory.
3. Open `output/corner/apollo-mount.FCStd` or another supplied CAD file in FreeCAD. Use **File → Open**, not Import of an STL.
4. Use **File → Save As** to save a working copy if you want to preserve that preset. The macro still exports to `output/custom`; saving under a different name does not change its output destination.
5. Select the tree item labelled **Parameters – edit, then run Rebuild.FCMacro** (internal name `Parameters`). In the Property view, choose the **Data** tab. If hidden, enable **View → Panels → Property view** or **Combo view**, depending on your FreeCAD layout.

## Make your changes

Double-click the value beside a property. Groups include Mount, Clearances, Retention, Printing and Cable. Enter lengths in **millimetres** and angles in **degrees**, as plain numbers: these are float properties rather than unit-aware expressions.

For example, a corner model aimed mainly along one wall:

| Property | Example value |
|---|---:|
| Corner | Yes |
| CornerAngle | 90 |
| CornerSetback | 10 |
| Yaw | -39 |
| Pitch | 4 |
| RearChamberDepth | 10 |
| CableEnabled | No |

Press Enter or click another property to finish the edit. Boolean values use Yes/No, and `FastenerSize` offers an M2/M3 dropdown. Read-only calculated values cannot drive geometry: for example, change `RearChamberDepth`, not `BoardDistance`.

Yaw 0 faces perpendicular to a flat wall, or along the bisector of an inside corner. Positive yaw points along the model's +X direction; positive pitch points downward. When looking at the back of the model, visual left/right is reversed. Use the PCB/front-cover direction in the 3D view to confirm the sign for your installation. Pitch is not the corner angle.

## Rebuild: the essential step

1. Activate the tab containing your working Apollo model. With several documents open, the active tab is the one the macro reads.
2. Open **Macro → Macros…**.
3. Set the macro location/user macros path to the repository root if needed, so `Rebuild.FCMacro` appears. Select it and click **Execute**. Alternatively open the macro file through FreeCAD's macro editor and execute it there.
4. Wait for the geometry operations and exports to finish. Complex angles/cable routes can take tens of seconds or longer; avoid starting a second rebuild.
5. Look for the **“Apollo rebuilt…”** success message in the status bar/Report view. The visible body and lid should update. Use **View → Standard views → Fit all** if the new position is off-screen.
6. Inspect the PCB grip, module space, mounting-wall clearance and cable route before slicing.

**Changing a parameter, saving the file, or pressing Recompute/F5 is not enough. Run the macro.** The geometry comes from the Python generator; FreeCAD does not automatically call it when a float property changes.

The published examples share [one lid download](../output/lid.stl); only their bodies differ. A rebuild still exports both body and lid so that changes to dimensions, PCB fit or fasteners have a matching pair. For printing, use only those two STL files.

The macro saves and writes the following into `output/custom/`, overwriting matching files:

| File | Purpose |
|---|---|
| `apollo-mount.FCStd` | Editable inputs, native solids and reference objects |
| `body.stl`, `lid.stl` | Individual parts oriented for slicing |
| `body.step`, `lid.step` | Oriented CAD solids for exchange |
| `assembly.step` | Body and cover in assembled positions; no reference PCB/cable |

It does **not** update an Orca project, reslice, send a print, rerun stress tests, or refresh old PNG previews. Import the new STLs or use your slicer's replace/reload feature and inspect orientation/supports again. Do not manually export all visible objects: that would risk including PCB/cable references.

## Keep multiple locations

After a successful rebuild:

1. Copy the whole `output/custom` folder to a new folder such as `output/living-room` using your file manager.
2. Open that folder's `.FCStd` when you next want to edit its parameters.
3. Rebuild still writes into `output/custom`; copy the new exports back to the named folder after checking them.

The snapshot includes both compatible body and lid. Mounting-angle changes use the same lid as the supplied examples. If you change fasteners, PCB fit or enclosure dimensions, use the newly exported matching lid; the published shared lid may no longer fit. Keep the complete parameter set with the CAD file, rather than recording only yaw and pitch.

## Reference visibility

Select a tree object and press **Space**:

- `SourcePCB`: original component/PCB mesh, missing the optional daughterboards.
- `Cover`: generated front cover; normally transparent after rebuilding.
- `ModuleClearance`: orange envelope reserved for components.
- `CablePreview`: actual cable diameter, shown only when cable processing is enabled.
- `PlugClearance`: provisional plug/boot envelope.
- `CableCentreline`: routing curve.

The supplied examples start with **CableEnabled = No**. To add cable routing, set it to **Yes** and run the macro.

Hiding a cable preview does **not** disable cable processing. Set `CableEnabled = No` and rebuild to remove routing constraints, cutouts and reinforcement. No cable tube is printed.

## If rebuilding fails

- **Nothing changed:** finish the property edit, select the correct active document, then execute the macro rather than just recomputing. Check **View → Panels → Report view**.
- **No Parameters object:** open a supplied `.FCStd`, not an imported STL/STEP or the PCB-only reference.
- **qconvex not found:** install Qhull and ensure FreeCAD can find that executable. Restart FreeCAD after changing its environment.
- **FreeCAD module cannot be imported in a terminal:** use FreeCAD's GUI macro, or configure the matching Python/module paths for your installation. Ordinary `pip install` is not the solution.
- **Source OBJ missing on a new build:** decompress `r-pro-1-pcb.obj.gz` to `r-pro-1-pcb.obj` in the repository root. On Linux use `gzip -dk r-pro-1-pcb.obj.gz`; an archive utility also works. The `.mtl` file referenced in the OBJ is absent; the scripts use geometry and assign their own display colours.
- **Invalid clearance, bend radius or solid:** follow the specific error message. Change the conflicting parameters or disable the cable if it will not be used. Do not remove validation checks to force an export.
- **Old geometry still visible after an error:** it represents the previous successful build, not the newly entered values. Existing or partly written exports must not be treated as a successful new build. Correct the problem and rerun until success.

The supported numeric ranges are described in the [parameter reference](PARAMETERS.md). A value being within range does not guarantee every combination will produce printable geometry.

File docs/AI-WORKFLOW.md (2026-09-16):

# Changing this design with AI

## Start with parameters in FreeCAD

For routine changes to angle, fit, cable routing or fasteners, use the [FreeCAD workflow](FREECAD.md): edit **Parameters → Data**, then run **Rebuild.FCMacro through Macro → Macros… → Execute**. An AI can help choose values or explain an error while you perform these steps. You do not need an AI with terminal access just to get advice on parameter values.

Use source edits when the desired feature is not covered by existing parameters. The Python and command-line recipes below are advanced alternatives for development or explicit automation requests.

## What the AI needs for source changes

Use an assistant that can read/edit the cloned repository and run local terminal commands. FreeCAD and Qhull must be installed on that computer. A FreeCAD MCP server is **not required**: the generator calls FreeCAD's Python API directly. An assistant without file/terminal access can propose a patch, but cannot claim to have built or tested it.

Start by asking it to read `README.md`, `AGENTS.md`, `docs/PARAMETERS.md`, `build_mount.py` and `Rebuild.FCMacro`. Give it the **exact saved CAD file** and the change you want. Saved values may differ from defaults; existing custom parameters must be read from that document.

### Example: another installation, no design change

> I'm editing `output/corner/apollo-mount.FCStd` in FreeCAD. Guide me through setting Yaw=-25, Pitch=8 and RearChamberDepth=20 in Parameters → Data while preserving all other settings. Then explain how to execute Rebuild.FCMacro inside FreeCAD, inspect the result and copy output/custom to output/study-corner so I can keep it. Use the existing parameters rather than changing Python defaults.

### Example: change the physical design

> Read this repository's parameter guide. I want to enlarge the CO2 holder notch by 0.2 mm on each side. Help me identify the current CO2ReliefClearance value in FreeCAD and increase it by 0.2, preserving every other value. Walk me through running Rebuild.FCMacro from FreeCAD and checking the outer wall and PCB support remain intact before printing a fit sample.

### Example: add a new capability

> Add [specific feature] to the shared generator. Trace how it affects the body, cover, references and exports. Keep existing parameter values compatible. Add an exposed setting only if users need to configure it. Update the parameter guide and add a small regression check that catches the original problem. Validate flat, corner and the affected extreme-angle examples. Regenerate only the agreed outputs after checking them.

Supply measured dimensions, the PCB face used as a datum, a photo with the relevant feature marked, desired units, and the physical purpose. Avoid requests such as “make it stronger” without identifying a load, a weak feature or a observed failure.

## Source map

| File/function | Responsibility |
|---|---|
| `build_mount.py:PARAMETERS` | Names, defaults, UI groups and tooltips |
| `defaults()` / `read_parameters()` | New-build defaults and saved-document values/legacy migration |
| `build()` | Solid construction, orientation, chamber, rails, screws, ventilation and cable geometry; validates the result |
| `parameters()` | Creates/updates FreeCAD editable and calculated properties |
| `export()` | Updates native objects; creates oriented body/lid STL/STEP; saves the CAD document |
| `main()` | CLI arguments or active GUI-document workflow |
| `Rebuild.FCMacro` | Runs the generator and presents success/failure in FreeCAD |
| `prepare_reference.py` | Imports the upstream multi-object PCB mesh into a reference document |
| `test_wall_offsets.py` | Independent corner-wall offsets, unchanged frame/lid and printable exports |
| `test_mount.py` | Geometry, retention, routing and export checks |
| `test_lid_thickness.py` | Compares the actual cover skin with the supplied Apollo front case |
| `test_strength.py`, `compare_corner_strength.py` | Optional structural screening; not part of normal rebuilds |

OpenCascade solid operations in FreeCAD include boxes, cylinders, lofts, offset surfaces, fuses and cuts. Qhull computes the convex rear-chamber envelope. Actual PCB grip geometry remains rigid while the chamber connects it to the mounting frame.

Manual edits to generated Mount/Cover solids will be overwritten by the next rebuild. Implement persistent changes in the generator or its parameter inputs.

## Advanced command-line builds

The normal parameter-editing workflow remains inside FreeCAD. For automation, clone the repository or use the extracted ZIP:

```sh
git clone https://github.com/ThomasHFWright/apollo-3d-enclosure.git
cd apollo-3d-enclosure
gzip -dk r-pro-1-pcb.obj.gz
python -c 'import build_mount; print(build_mount.App.Version())'
qconvex -V
python build_mount.py --corner --set Yaw=-39 --set Pitch=4 --set RearChamberDepth=1 --set CableEnabled=false --name my-corridor
```

Terminal builds require a Python interpreter compatible with the installed FreeCAD modules and `qconvex` on PATH. The scripts add `/usr/lib/freecad/lib`; other installation layouts may require adapting that path. FreeCAD GUI builds use FreeCAD's own Python. No pip package replaces the FreeCAD installation.

The compressed reference is about 13 MB and expands to about 89 MB; no Git LFS is required. New CLI documents need the decompressed OBJ; supplied CAD files already embed it.

This command creates `output/my-corridor/` with CAD, STL and STEP files. Repeat `--set` for editable parameters; booleans are `true`/`false`. Choose a simple new folder name for `--name` to avoid overwriting another build. CLI builds start from **source defaults**, not the currently open or saved model. Use FreeCAD or the saved-document recipe below to preserve existing settings.

## Advanced: preserve a saved model from Python

Run this from the repository root using a Python compatible with FreeCAD. Choose a new destination; `export()` overwrites its named files.

```python
from pathlib import Path
import build_mount as m

source = m.ROOT / 'output/corner/apollo-mount.FCStd'
target = m.ROOT / 'output/study-corner'
assert not target.exists(), 'Choose a new output folder'
doc = m.App.openDocument(str(source))
p = m.read_parameters(doc)          # Preserve the saved settings, not defaults.
p.update(Yaw=-25., Pitch=8., RearChamberDepth=20.)
result = m.build(p)                 # Validate before replacing document geometry.
m.parameters(doc, p)
m.export(doc, p, result, target)
assert len(result['body'].Solids) == len(result['lid'].Solids) == 1
m.App.closeDocument(doc.Name)
```

The GUI macro already reloads `build_mount.py` on each execution. In a long-lived Python console, use `importlib.reload(build_mount)` after source edits to avoid testing stale code.

## Required verification

1. Record the source document and complete parameter set before editing.
2. Keep changes in the shared generator so CLI and GUI follow the same geometry rules.
3. Build the affected configuration into a separate folder. Never suppress a geometry error to force an export.
4. Run the relevant existing checks. For a CO₂ change, for example:

```python
import test_mount
# p and result come from the saved-document recipe above.
test_mount.check_co2_relief(p, result)
```

5. For wider generator changes, run `python test_mount.py`. Run `python test_lid_thickness.py` when the cover changes. For a small parameter adjustment, the generator/export checks and relevant fit checks are more useful than blindly running every historical simulation.
6. Inspect rendered views or the native FreeCAD model. Confirm clearances, connected material around cutouts, reinforcement and references. Verify both body and cover.
7. Slice for the actual printer and orientation. Review the first unsupported layer under each large span, not just the final support silhouette.
8. Report what was changed, which tests passed, what was actually printed, and what remains provisional. A screenshot or low FEM stress alone is not evidence of a successful physical fit or long-term heat resistance.

Do not change another saved preset merely because it has different parameters. Do not replace a user's latest Orca arrangement with an older example or silently inherit old toolpaths. The geometry exports are separate from slicer projects. Published body examples share `output/lid.stl` and `output/lid.step`; avoid publishing duplicate lids for mounting-angle variants. Keep both parts in generated custom exports because dimension or fastener changes can require a different lid.

## Structural screening

The FEM scripts use FreeCAD FEM, Gmsh and CalculiX. Binaries/solver environments and large result files are intentionally not distributed. `test_strength.py` currently expects `/usr/bin/gmsh`, FreeCAD FEM at `/usr/lib/freecad/Mod/Fem`, and CalculiX at `.tools/fem/bin/ccx`. On a compatible Linux installation with `ccx` already installed, the last path can be supplied with a local symlink:

```sh
mkdir -p .tools/fem/bin
ln -s "$(command -v ccx)" .tools/fem/bin/ccx
python test_strength.py --benchmark
```

Check that `command -v ccx` returns a path first. Other systems should adapt the explicit paths in the scripts. The benchmark compares a simple axial test with its analytical result. The flat-body fixture rejects corner or tilted models; do not bypass that guard.

```sh
python test_strength.py --case body-weight --source output/flat/apollo-mount.FCStd --size 2
python compare_corner_strength.py --variant ends --case side --size 2 --linear-edges
```

The corner script reads `output/Final-prints/entrance.FCStd` and requires Corner=Yes and CableEnabled=No. It compares end closures with an optional spine. Re-running it on a newly aimed entrance model is a **new experiment**, not reproduction of earlier numerical values. `ViewStrength.FCMacro` can show a resulting `strength.FCStd`; it is not an enclosure rebuild macro.

Assumptions include isotropic fully solid linear elasticity, an elastic-modulus proxy and fixed wall-screw bores. Sliced infill, layer anisotropy, wall compliance, screw preload, temperature and PETG creep are not modelled. Mesh failures must be reported, and stress peaks at sharp edges need mesh-sensitivity checks. Rebuilding CAD does not rerun FEM.

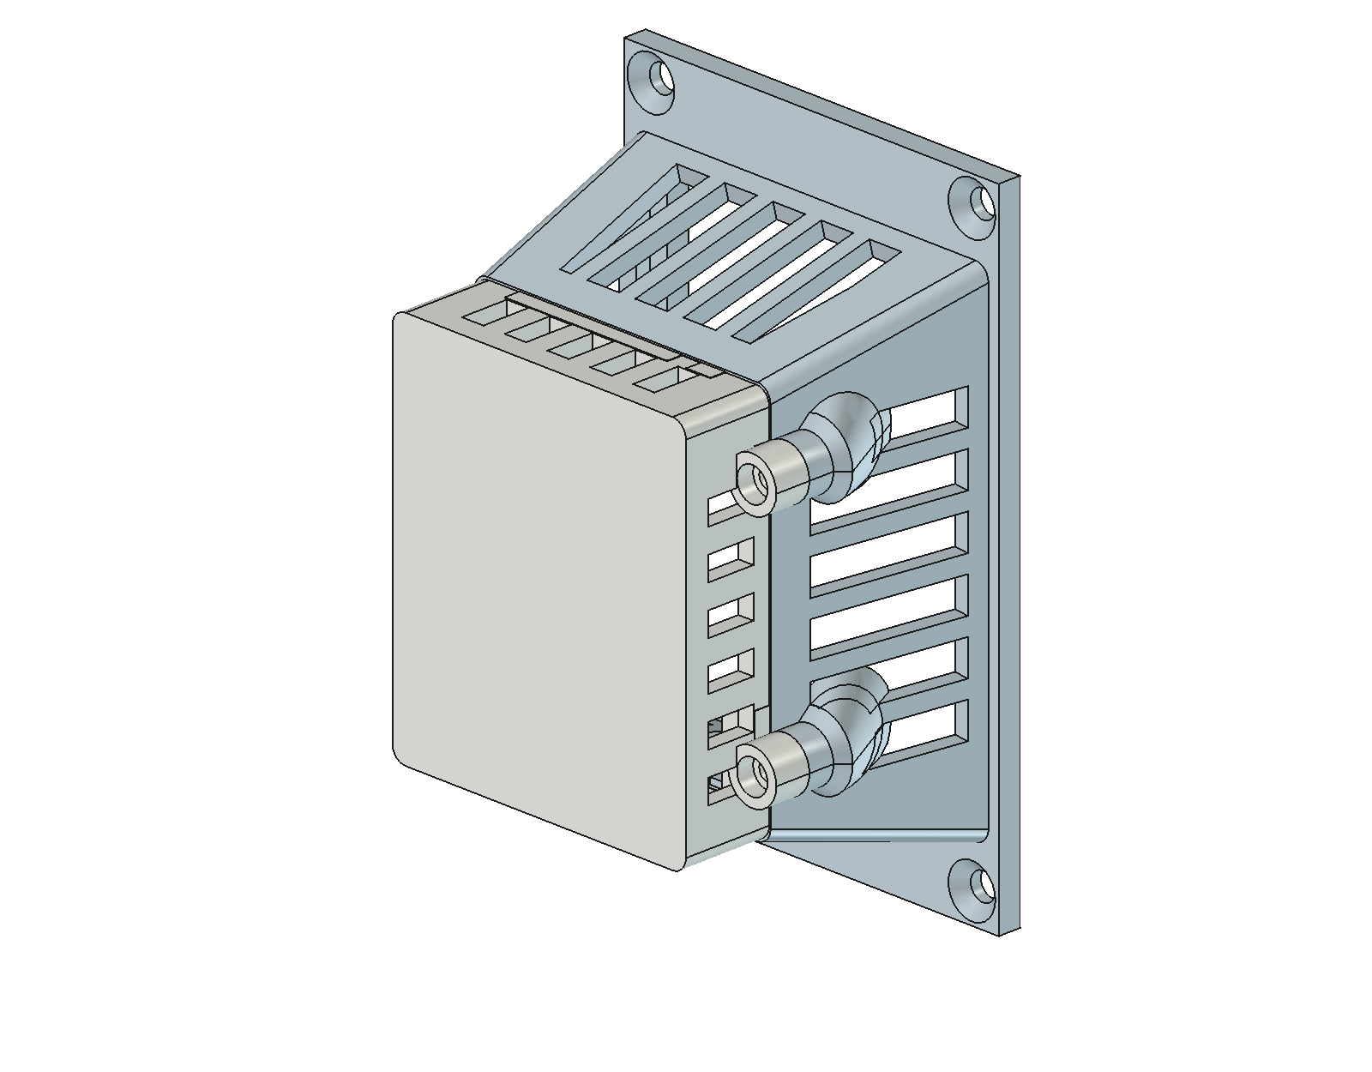
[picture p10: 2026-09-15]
docs/images/flat.png

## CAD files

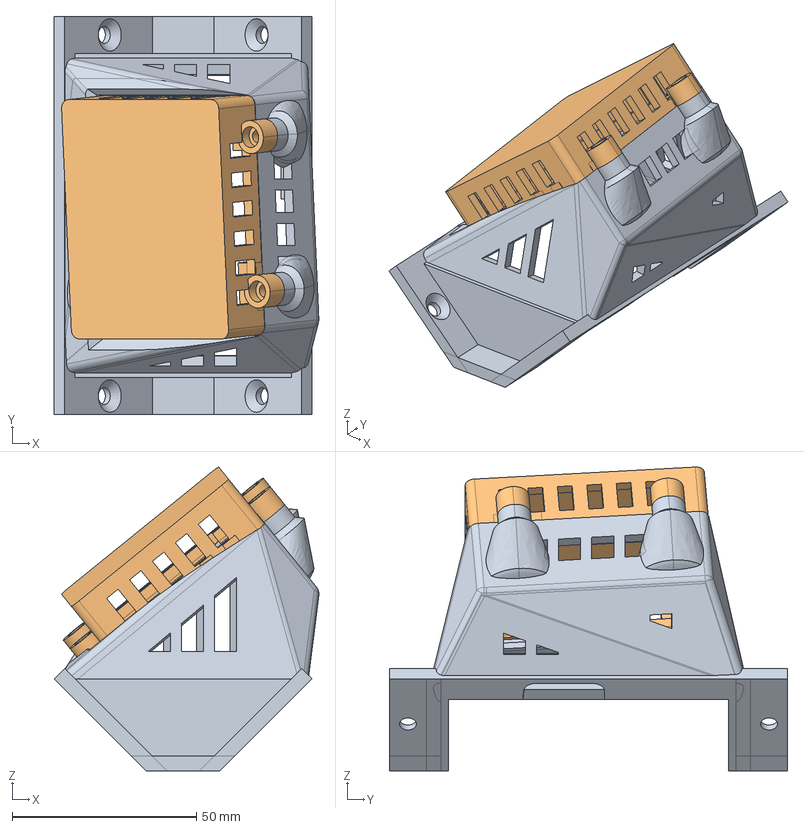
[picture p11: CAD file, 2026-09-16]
output/compact-corner-poe/assembly.step
71.8 x 108.0 x 82.5 mm

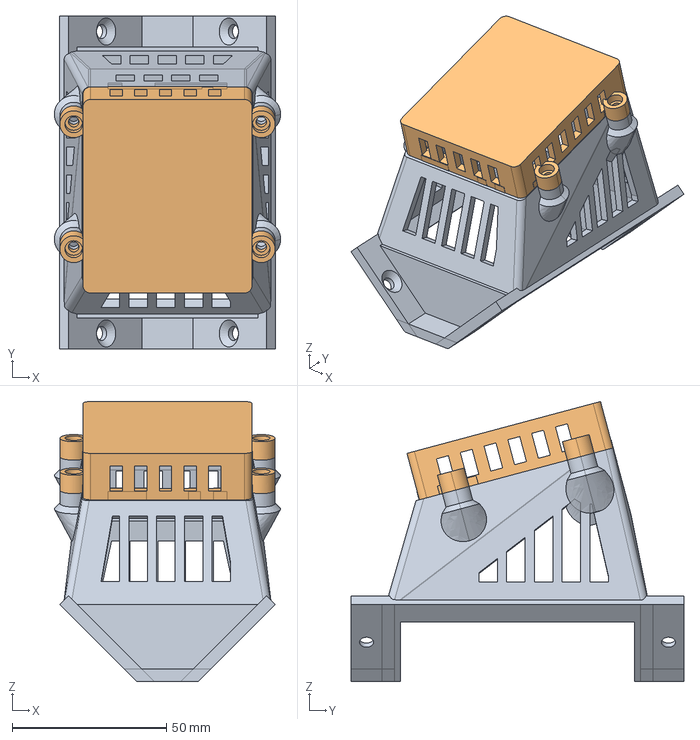
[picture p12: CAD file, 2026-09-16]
output/corner/assembly.step
73.5 x 108.0 x 90.9 mm

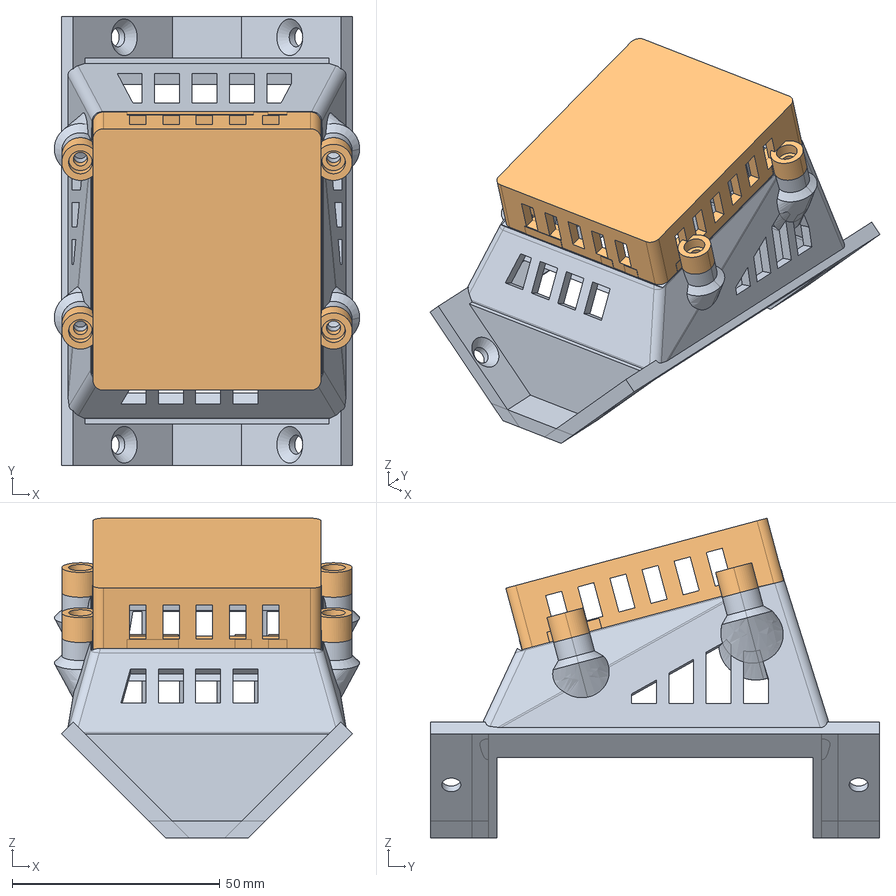
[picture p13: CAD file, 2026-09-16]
output/compact-pitch15/assembly.step
73.5 x 108.0 x 76.9 mm

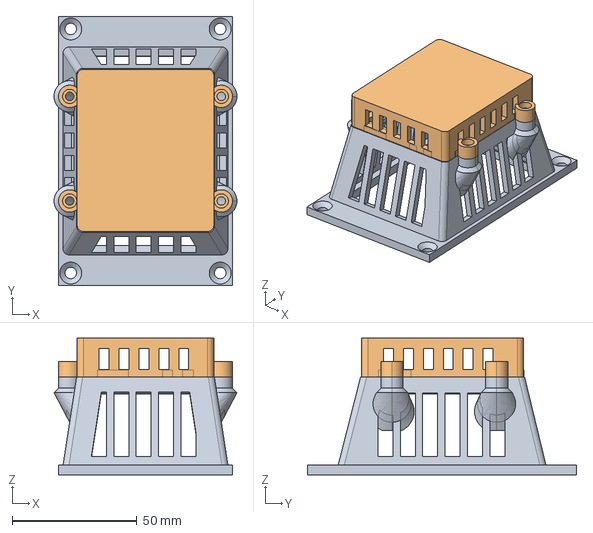
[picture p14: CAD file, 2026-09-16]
output/flat/assembly.step
73.5 x 108.0 x 54.9 mm

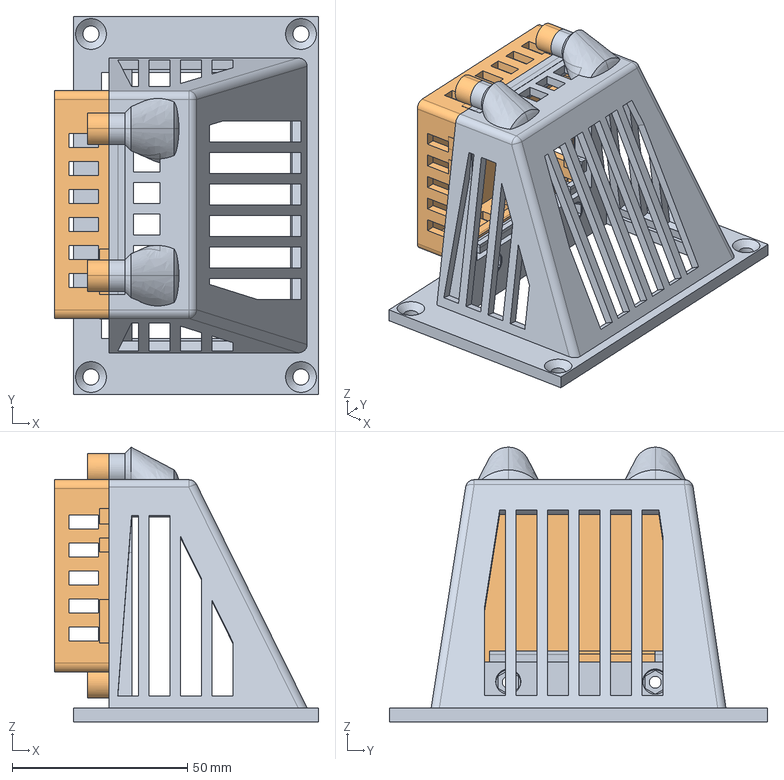
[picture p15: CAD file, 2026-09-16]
output/yaw_minus90/assembly.step
75.4 x 108.0 x 78.5 mm

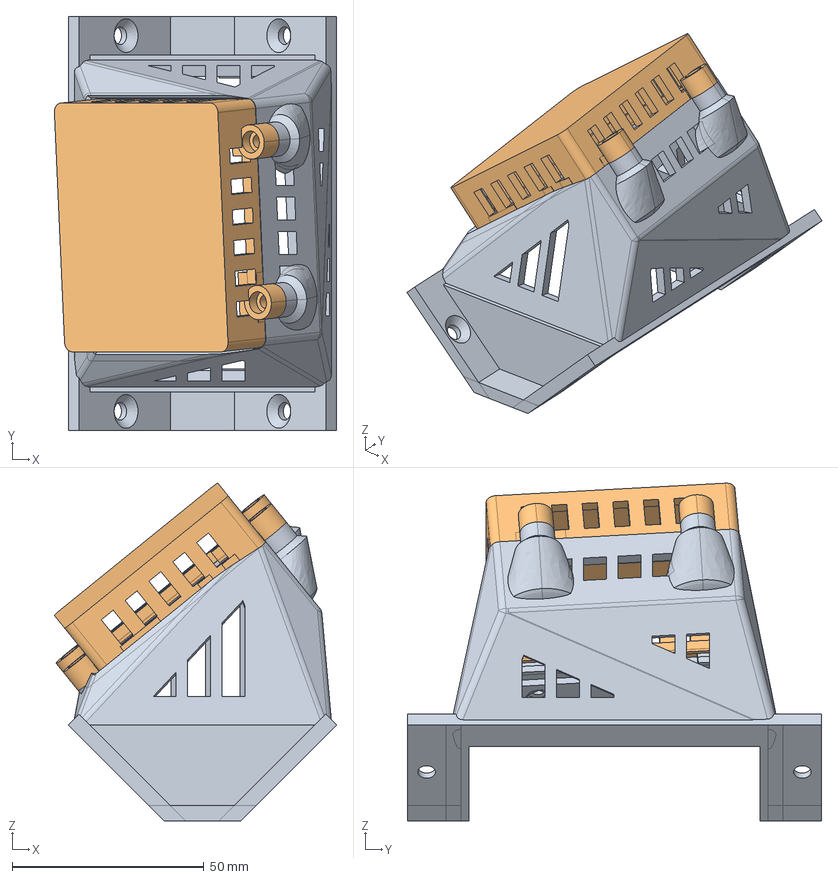
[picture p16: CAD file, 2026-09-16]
output/custom/assembly.step
73.6 x 108.0 x 88.1 mm

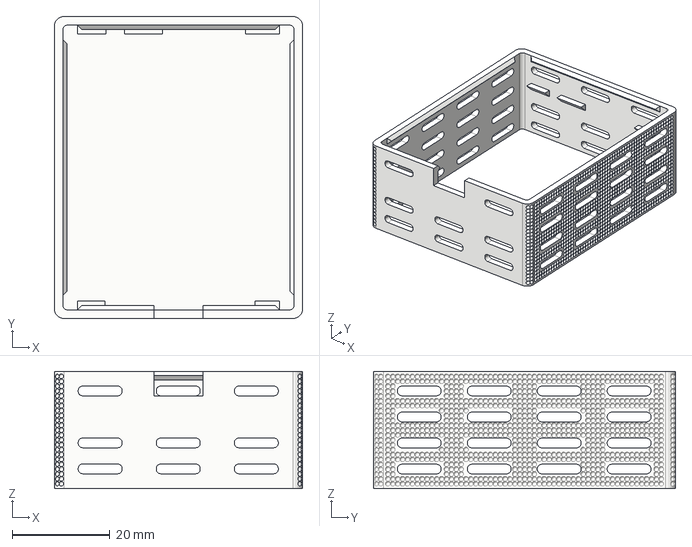
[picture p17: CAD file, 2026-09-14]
apollo-automation-r-pro-1-dual-mmwave-multisensor-with-optional-co2-addon-model_files/r_pro-1_case.step
50.9 x 61.9 x 24.0 mm

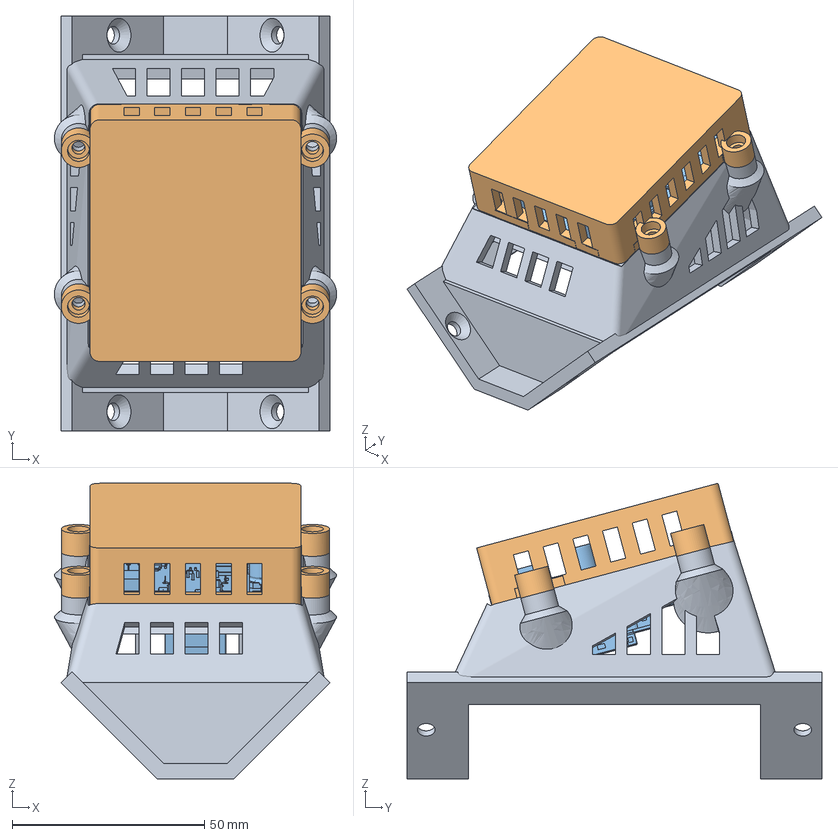
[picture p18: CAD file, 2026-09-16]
output/compact-pitch15/apollo-mount.FCStd
73.5 x 108.0 x 76.9 mm
Structural mount - one printed part
Front cover and PCB keepers
Original PCB mesh - radar and CO2 boards absent

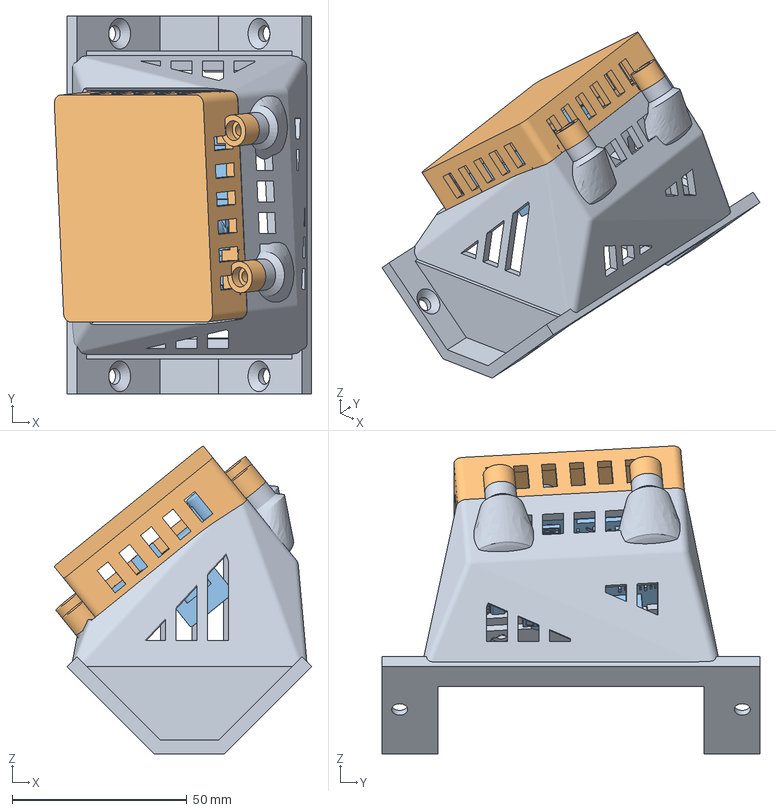
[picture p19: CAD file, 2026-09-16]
output/custom/apollo-mount.FCStd
73.6 x 108.0 x 88.1 mm
Structural mount - one printed part
Front cover and PCB keepers
Original PCB mesh - radar and CO2 boards absent

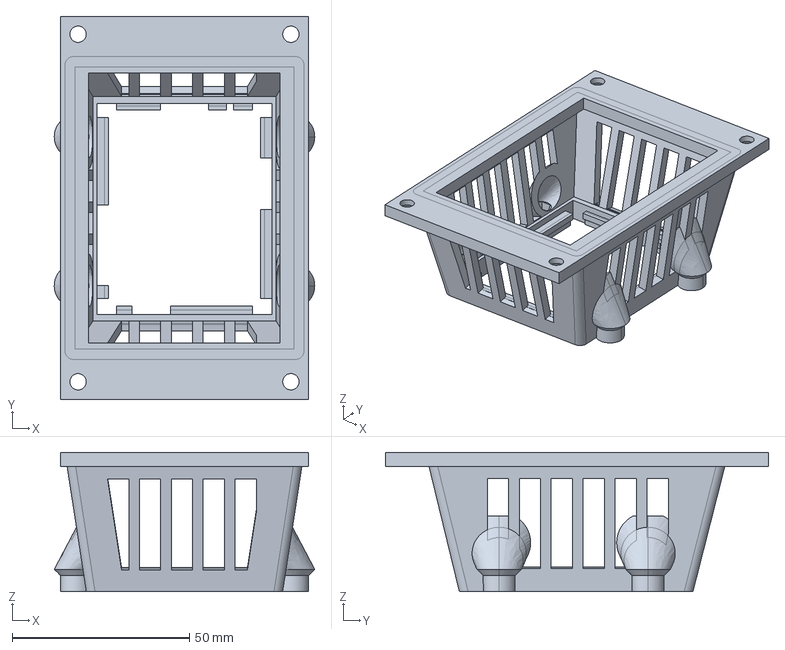
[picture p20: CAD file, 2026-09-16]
output/flat/body.step
73.5 x 108.0 x 39.3 mm

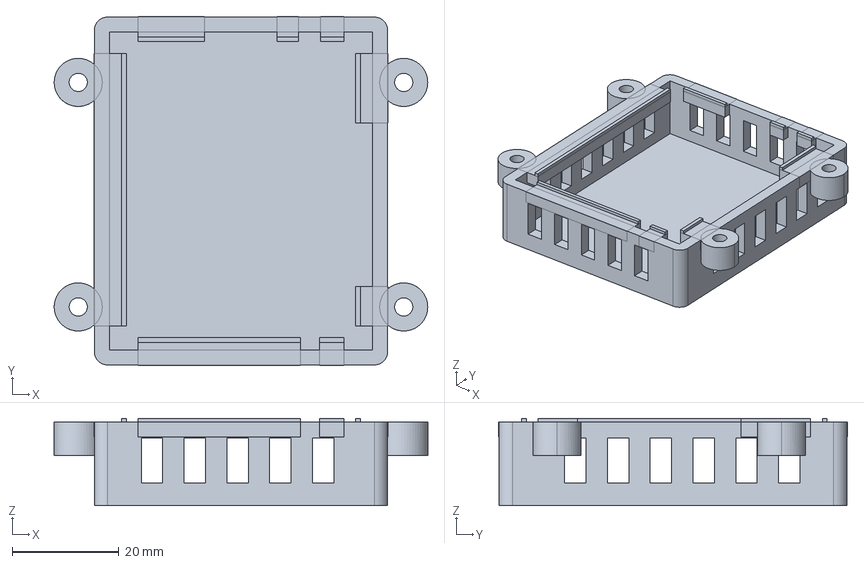
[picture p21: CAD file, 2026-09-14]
output/lid.step
69.9 x 65.3 x 16.3 mm

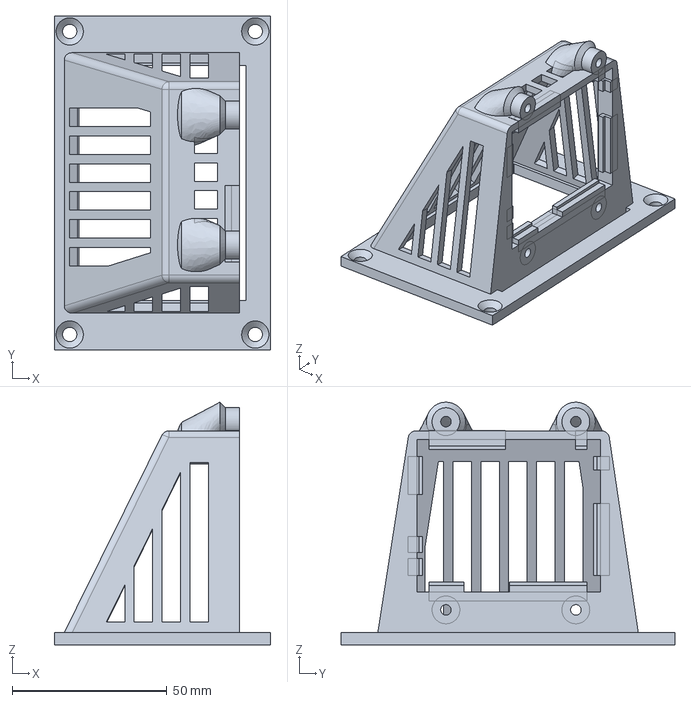
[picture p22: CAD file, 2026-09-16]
output/yaw90/body.step
70.0 x 108.0 x 78.5 mm

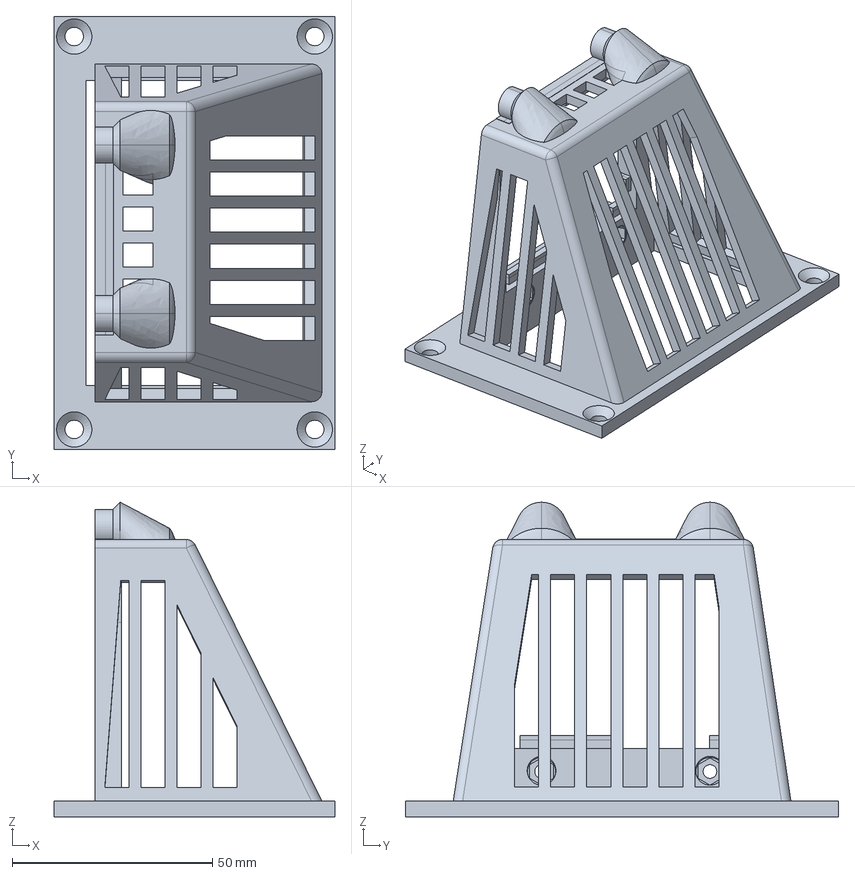
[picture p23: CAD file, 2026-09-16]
output/yaw_minus90/body.step
70.0 x 108.0 x 78.5 mm

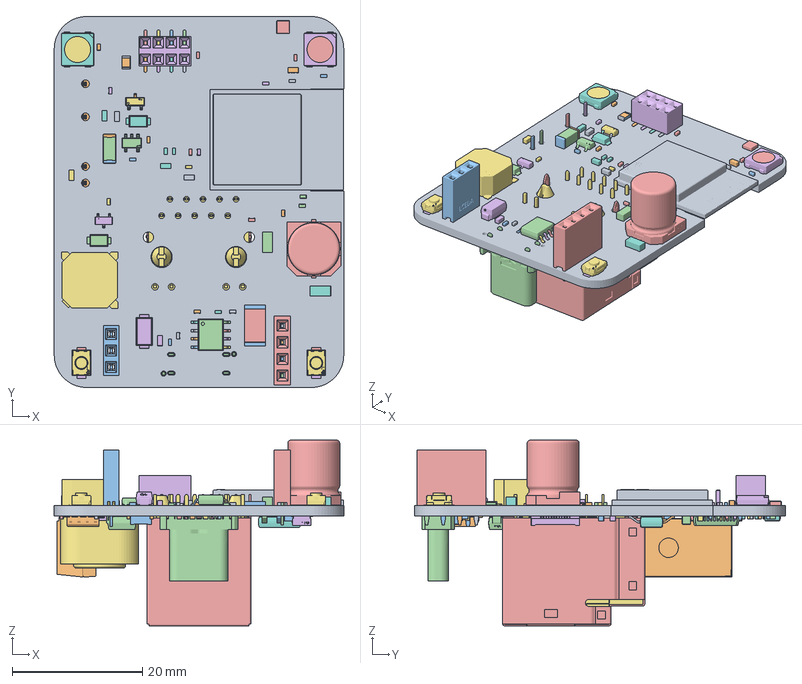
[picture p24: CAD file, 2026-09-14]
r-pro-1-pcb-reference.FCStd
44.5 x 57.0 x 28.5 mm
Main PCB (source mesh, millimetres assumed)
r-pro-1-pcb001
r-pro-1-pcb002
r-pro-1-pcb003
r-pro-1-pcb004
r-pro-1-pcb005
r-pro-1-pcb006
r-pro-1-pcb007
r-pro-1-pcb008
r-pro-1-pcb009
r-pro-1-pcb010
r-pro-1-pcb011
r-pro-1-pcb012
r-pro-1-pcb013
r-pro-1-pcb014
r-pro-1-pcb015
r-pro-1-pcb016
r-pro-1-pcb017
r-pro-1-pcb018
r-pro-1-pcb019
r-pro-1-pcb020
r-pro-1-pcb021
r-pro-1-pcb022
r-pro-1-pcb023
r-pro-1-pcb024
r-pro-1-pcb025
r-pro-1-pcb026
r-pro-1-pcb027
r-pro-1-pcb028
r-pro-1-pcb029
r-pro-1-pcb030
r-pro-1-pcb031
r-pro-1-pcb032
r-pro-1-pcb033
r-pro-1-pcb034
r-pro-1-pcb035
r-pro-1-pcb036
r-pro-1-pcb037
r-pro-1-pcb038
r-pro-1-pcb039
r-pro-1-pcb040
r-pro-1-pcb041
r-pro-1-pcb042
r-pro-1-pcb043
r-pro-1-pcb044
r-pro-1-pcb045
r-pro-1-pcb046
r-pro-1-pcb047
r-pro-1-pcb048
r-pro-1-pcb049
r-pro-1-pcb050
r-pro-1-pcb051
r-pro-1-pcb052
r-pro-1-pcb053
r-pro-1-pcb054
r-pro-1-pcb055
r-pro-1-pcb056
r-pro-1-pcb057
r-pro-1-pcb058
r-pro-1-pcb059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

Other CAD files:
output/yaw90/assembly.step
output/compact-corner-poe/apollo-mount.FCStd
output/corner/body.step
output/Final-prints/entrance.stl
output/compact-corner-poe/body.step
output/compact-corner-poe/body.stl
output/compact-pitch15/body.step
output/compact-pitch15/body.stl
output/corner/apollo-mount.FCStd
output/corner/body.stl
output/custom/body.step
output/custom/body.stl
output/flat/apollo-mount.FCStd
output/flat/body.stl
output/lid.stl
output/yaw90/apollo-mount.FCStd
output/yaw90/body.stl
output/yaw_minus90/apollo-mount.FCStd
output/yaw_minus90/body.stl

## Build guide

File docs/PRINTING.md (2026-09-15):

# Printing, fit and assembly

## Two files to print

Download the **[shared lid.stl](../output/lid.stl)** and **one body STL** from the [body examples](../README.md#body-examples--choose-one). Print one body and one lid. The other body downloads are alternative mounting shapes and angles, not extra assembly pieces. All supplied body examples use this same lid.

CAD/STEP files, reference meshes and scripts are only needed for editing/development. If you rebuild with changed dimensions, PCB-fit or fastener settings, use the matching lid generated by that rebuild.

## Printer and filament

The working setup is a Bambu Lab A1 with a 0.4 mm nozzle and white ELEGOO Rapid/Fast PETG. Start from the appropriate manufacturer/system filament profile in your slicer. The tested OrcaSlicer 2.4.2 setup used its bundled **Elegoo Rapid PETG @System** profile (250°C nozzle, 70°C bed) and these process settings:

| Setting | Working value |
|---|---|
| Layer height / first layer | 0.24 / 0.20 mm |
| Walls | 4 |
| Top / bottom layers | 5 / 5 |
| Sparse infill | 25% gyroid |
| Outer / inner wall speed | 60 / 100 mm/s |
| First layer / first-layer infill | 25 / 40 mm/s |
| Body supports | Tree auto, allowed on the model as well as the bed |
| Support top / bottom gap | 0.2 / 0.2 mm |
| Support top interface layers | 3 |
| Support XY gap | 0.35 mm |
| Brim | 5 mm when needed for adhesion |

These are starting settings for that setup, not a universal PETG profile. Calibrate and dry according to your actual filament/printer guidance. A different print orientation or larger angle can substantially change support needs.

## Orientation and exports

The generator orients the body with the PCB rim toward the bed when possible; at steep angles it switches to a wall-contact face to keep all material above the bed. The lid is exported exterior face down. Check the first layer and support access in the slicer rather than assuming exported orientation is always the most economical.

Import `body.stl` and `lid.stl` as separate printable parts at 100% scale, in millimetres. Do not slice `SourcePCB`, the cable preview or orange clearance envelopes. Native CAD and `assembly.step` show assembled positions; individual STL/STEP exports are oriented for printing. The automated bed check is for a 256 mm cube; smaller printers need their own check.

## Hardware

- Four standard M3 hex nuts by default; pockets are 5.9 mm across flats and 2.9 mm deep.
- Four matching M3 bolts. M3×12 mm was checked for the developed corner arrangement; verify engagement and protrusion for your variant. M3×8 mm provided only about 1.1 mm engagement in the checked arrangement and was too short.
- Head recesses default to 5.7 mm diameter × 3.0 mm depth, based on measured heads of 5.3 × 2.8 mm plus clearance.
- Four wall screws/anchors suitable for your wall. The printed wall holes are 4.6 mm with countersunk entrances; wall hardware is separate from the M3 cover bolts.

M2 is available in the FastenerSize dropdown; change both body and lid together and measure the matching heads. Ordinary hex nuts are assumed, not nyloc. Fastener clearance is a print-tolerance allowance, not guaranteed fit for every machine.

## Fit and assembly

1. Print **one chosen body and the shared lid** (or your rebuilt matching pair), then remove supports.
2. With the device unpowered, check the main PCB seats freely, all daughterboards/pins clear the plastic, and the CO₂ notch reaches the inner wall without interference. Only the main PCB edges should be retained.
3. Test nuts, bolt holes and head recesses. Adjust the relevant clearance parameters and rebuild if required; do not clamp a bent PCB into place.
4. Check access through the finger pockets and the complete cable route with your actual hardware.
5. Place nuts into the rear-facing pockets through the chamber before installing the PCB. Confirm access with fingers or tweezers.
6. Check your Ethernet male connector and boot pass through the opening and can negotiate the route. A cross-section clearance check alone does not prove a rigid connector can move around every bend. Arrange cable insertion and wall fastening while the PCB is accessible.
7. Attach the body to the wall, seat the PCB on its ledges, and gently tighten the lid until its flanges seat. Check bolt tips and heads clear the electronics.
8. Keep ventilation open around the PoE hardware and CO₂ sensor. Check operation, radar coverage, physical fit and retention during sustained use before printing a batch.

The 1.2 mm front skin measured thinner than the supplied official front's minimum 1.25 mm. This is a geometry comparison, not an RF attenuation measurement. White unfilled PETG was the intended material; other colours/fillers and sensor revisions may behave differently.

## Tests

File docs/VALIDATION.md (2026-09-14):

# Publication checks — 15 September 2026

Environment: FreeCAD 1.1.3, Qhull, system Python, CachyOS/Linux.

The selected repository files were copied to a fresh temporary directory to check that local caches and untracked model files were not needed for the documented workflow.

- All 58 editable source parameters occur exactly once in the parameter-reference tables. Twelve calculated properties are documented separately.
- Relative Markdown file links resolve to included files. Native CAD ZIP containers pass integrity checks. Selected files are below GitHub's per-file limit.
- Compressed PCB reference decompresses successfully; a fresh CLI build of the corridor example passes the generator/export checks: valid connected body/lid, no reserved-module/wall/cover collision, closed printable meshes and bed bounds.
- `python test_lid_thickness.py` passes for all six supplied CAD documents: 1.20 mm front skin versus the official reference's 1.25 mm minimum.
- The actual `Rebuild.FCMacro` is tested in FreeCAD's GUI on a virtual display: load the corner preset, change yaw/pitch/depth/cable settings, regenerate, verify the complete parameter set is preserved except for those requested changes, and check the CO₂ relief.

This publication does not introduce enclosure geometry changes. The full historical geometry suite and FEM comparisons were not rerun for the documentation/publication task. No print was started. These checks do not establish physical fit, RF performance or lifetime under PoE heat.

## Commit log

2026-09-14 Publish configurable Apollo R PRO-1 enclosure, models and community guides
    [apollo-mount.FCStd, assembly.step, body.step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]
2026-09-15 Remove optional fit-ring exports and models
    [fit-ring.step, fit-ring.stl]
2026-09-15 Share one lid download across body examples
    [lid.step, lid.stl]
2026-09-15 Default to cable disabled and 10 mm rear chambers in standard examples
    [apollo-mount.FCStd, assembly.step, body.step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]
2026-09-15 Add opt-in compact corner placement and checked corridor example
    [apollo-mount.FCStd, assembly.step, body.step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]
2026-09-15 Keep compact corner backs open and check all saved models
    [apollo-mount.FCStd, assembly.step, body.step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]
2026-09-15 Let compact rear bays taper independently of the rigid PCB holder
    [apollo-mount.FCStd, assembly.step, body.step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]
2026-09-15 Preserve chamber walls outside the tilted lid footprint
    [apollo-mount.FCStd, assembly.step, body.step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]
2026-09-15 Keep compact corner lid above body and preserve wall screw pads
    [apollo-mount.FCStd, assembly.step, body.step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]
2026-09-15 Preserve corner wall-contact frame when trimming chamber for lid
    [apollo-mount.FCStd, assembly.step, body.step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]
2026-09-15 Close chamber-to-frame gaps with local corner reinforcement
    [apollo-mount.FCStd, assembly.step, body.step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]
2026-09-15 Taper corner reinforcement into lid seating surface
    [apollo-mount.FCStd, assembly.step, body.step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]
2026-09-16 Refresh all published CAD properties and prepare compact mounts for main
    [apollo-mount.FCStd, assembly.step, body.step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]
2026-09-16 Publish corridor mount example and wall-offset instructions
    [entrance.FCStd, entrance.stl]
